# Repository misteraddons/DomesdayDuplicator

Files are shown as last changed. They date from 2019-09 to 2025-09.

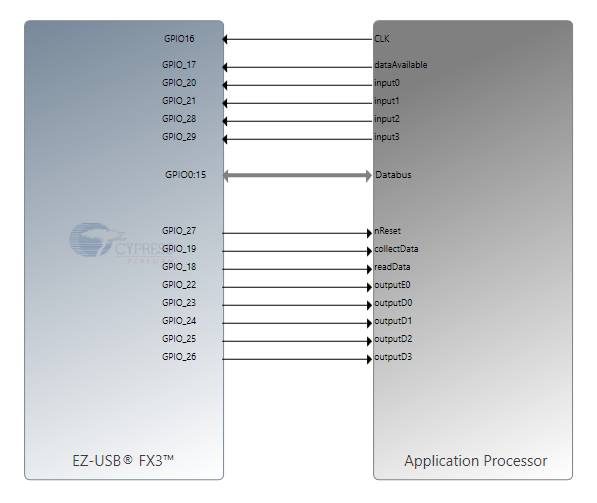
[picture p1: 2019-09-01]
Firmware/Cypress-FX3/GPIF_II/IO_Matrix_view.PNG

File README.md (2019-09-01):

# Domesday Duplicator

## Synopsis

The Domesday Duplicator is a USB3 based DAQ designed for the high-speed acquisition of analogue RF data.

The Domesday Duplicator was originally designed to allow the backup of Domesday AIV LaserDiscs (as well as generic laserdiscs) through the direct sampling of the RF data from the optical head (laser) of a LaserDisc player.  Since it's inception the project has expanded to include backup of other optical and magnetic media.

The hardware/software solution is designed to act as a sampling front-end to the ld-decode (software decode of laserdiscs) project https://github.com/happycube/ld-decode and can produce raw RF image files ready for software decoding.

Please see http://www.domesday86.com/?page_id=978 for detailed documentation on the Domesday Duplicator and overall information about the Domesday86 project.

There are several components that make up the Domesday Duplicator:

Terasic DE0-Nano FPGA development board - The DE0-Nano is a low-cost FPGA development board containing an Altera Cyclone IV FPGA.  The DE0-Nano is used to process the raw 10-bit ADC data stream and provides FIFO buffering (towards the FX3) and sample conversion from unsigned 10-bit to scaled 16-bit signed data.  The FPGA provides a dual-clock FIFO; receiving ADC data at a maximum of 40 MSPS (million samples per second) and transmitting the data to the FX3 at a maximum of 60 MSPS.  This is to ensure that no data is lost during sustained transfers (as RF sampling of a disc can take more than 40 minutes).

Cypress FX3 SuperSpeed Explorer board - The FX3 is a low-cost USB3 development board from Cypress.  The FX3 is used to buffer data from the FPGA and provide it to a host computer using USB3.  USB3 is required for this application due to the high-data bandwidth necessary for high-speed/high-resolution sampling.

Domesday Duplicator DE0-Nano base - This custom board provides the interface between the DE0-Nano and the Cypress FX3 board and contains 2 'slots' for Domesday Duplicator Modules.  As well as connectivity and databus routing the base board also contains the basic power supply circuitry for the modules.

Domesday Duplicator ADS825 module - A custom ADC board based around the Texas Instruments ADS825 10-Bit, 40MSPS analogue to digital converter. This board contains an RF amplifier and conditioner (to amplify the output from the laserdisc player RF tap and condition it for the single-ended ADC chip) as well as line-buffers to interface the ADC to the databus of the base board.

## Motivation

The Domesday86 project is involved in the documentation and preservation of the BBC Domesday Project from 1986.  The Domesday project provided a set of analogue laserdiscs in a proprietary format (like standard laserdiscs but with some specific extensions only supported by the Philips VP415 laserdisc player).

The Domesday Duplicator is intended to allow high-quality back-ups of the analogue information contained on the laserdiscs by bypassing most of the 30-year-old electronics in the VP415 player.  Direct RF sampling also allows all information on the laserdiscs to be stored (unlike conventional RGB sampling of the video output).  Since AIV laserdiscs are a combination of video, pictures, sound and data (as well as numerous VBI streams), direct RF sampling is the preferred method of preservation.

## Installation

Please see http://www.domesday86.com/?page_id=978 for detailed documentation on the Domesday Duplicator

## Author

Domesday Duplicator is written and maintained by Simon Inns.

## Software License (GPLv3)

    Domesday Duplicator is free software: you can redistribute it and/or modify
    it under the terms of the GNU General Public License as published by
    the Free Software Foundation, either version 3 of the License, or
    (at your option) any later version.

    Domesday Duplicator is distributed in the hope that it will be useful,
    but WITHOUT ANY WARRANTY; without even the implied warranty of
    MERCHANTABILITY or FITNESS FOR A PARTICULAR PURPOSE.  See the
    GNU General Public License for more details.

    You should have received a copy of the GNU General Public License
    along with this program.  If not, see <http://www.gnu.org/licenses/>.

## Hardware License (Creative Commons BY-SA 4.0)

Please see the following link for details: https://creativecommons.org/licenses/by-sa/4.0/

You are free to:

Share - copy and redistribute the material in any medium or format
Adapt - remix, transform, and build upon the material
for any purpose, even commercially.

This license is acceptable for Free Cultural Works.

The licensor cannot revoke these freedoms as long as you follow the license terms.

Under the following terms:

Attribution - You must give appropriate credit, provide a link to the license, and indicate if changes were made. You may do so in any reasonable manner, but not in any way that suggests the licensor endorses you or your use.

ShareAlike - If you remix, transform, or build upon the material, you must distribute your contributions under the same license as the original.

No additional restrictions - You may not apply legal terms or technological measures that legally restrict others from doing anything the license permits.

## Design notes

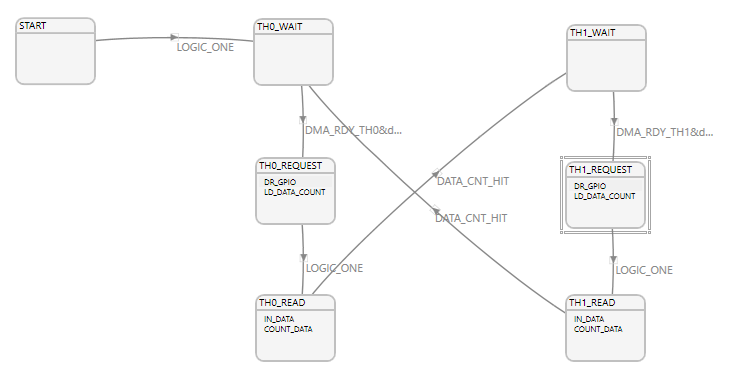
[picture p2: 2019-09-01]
Firmware/Cypress-FX3/GPIF_II/State_Machine_view.PNG

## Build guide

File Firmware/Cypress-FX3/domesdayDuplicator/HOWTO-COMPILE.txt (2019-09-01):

Setting up the Cypress tool-chain
=-=-=-=-=-=-=-=-=-=-=-=-=-=-=-=-=
Before compiling you must install the Cypress Linux SDK and follow the instructions in the 
FX3_SDK_Linux_Support PDF section 2.  The PDF is located in:

~/FX3_SDK_1.3.4_Linux/fx3_firmware_linux/cyfx3sdk

(Provided you copied the Cypress tarball to your home directory).

If you are running a 64-bit OS (which you should be) - follow section 2.1 step 3 and enter
the following command:

apt-get install lib32z1

No other parts of section 2.1 are required.

The section 2.2 instructions require you to set up a number of environment variables.  These
should be placed in your ~/.profile file so they are loaded everytime you log in.  The required
variables are as follows:

# Environment variables for Cypress FX3
export PATH=$PATH:$HOME/FX3_SDK_1.3.4_Linux/ARM_GCC/arm-2013.11/bin
export FX3_INSTALL_PATH=$HOME/FX3_SDK_1.3.4_Linux/fx3_firmware_linux/cyfx3sdk
export ARMGCC_INSTALL_PATH=$HOME/FX3_SDK_1.3.4_Linux/ARM_GCC/arm-2013.11
export ARMGCC_VERSION=4.8.1
export CYUSB_ROOT=$HOME/FX3_SDK_1.3.4_Linux/cyusb_linux_1.0.5

Once the environment variables are set (and you have loaded them by logging back into your
user account.  Compile the elf2img program as follows (section 2.1 step 7):

cd $FX3_INSTALL_PATH/util/elf2img
gcc elf2img.c –o elf2img –Wall

Compiling the Domesday Duplicator FX3 Firmware
=-=-=-=-=-=-=-=-=-=-=-=-=-=-=-=-=-=-=-=-=-=-=-
To compile the Domesday Duplicator FX3 firmware, first change directory to the source directory:

cd ~/github/FX3-Firmware/domesdayDuplicator

Then compile the firmware image using the command:

make all

Note: The Cypress version of Eclipse is *not* required.

Programming the FX3
=-=-=-=-=-=-=-=-=-=
To load the firmware onto the FX3 device use the Cypress cyusb_linux tool (please see the cypress
documentation for installation instructions).  The steps are as follows:

 1. Close/short jumper J4 (PMODE) on the FX3 Superspeed board
 2. Power off the FX3 and then power it on again
 3. Load the cyusb_linux application
 4. Highlight the FX3 bootloader device at the top of the window
 5. Click on the ‘program’ tab
 6. Select I2C EEPROM
 7. Click on ‘select file’ and select the FX3 programming file from disk (use the .img file from the Release directory)
 8. Click on ‘Start download’ to write the programming file to the device
 9. Wait for programming to complete
10. Remove the jumper from J4
11. Power off the FX3 and then power it on again

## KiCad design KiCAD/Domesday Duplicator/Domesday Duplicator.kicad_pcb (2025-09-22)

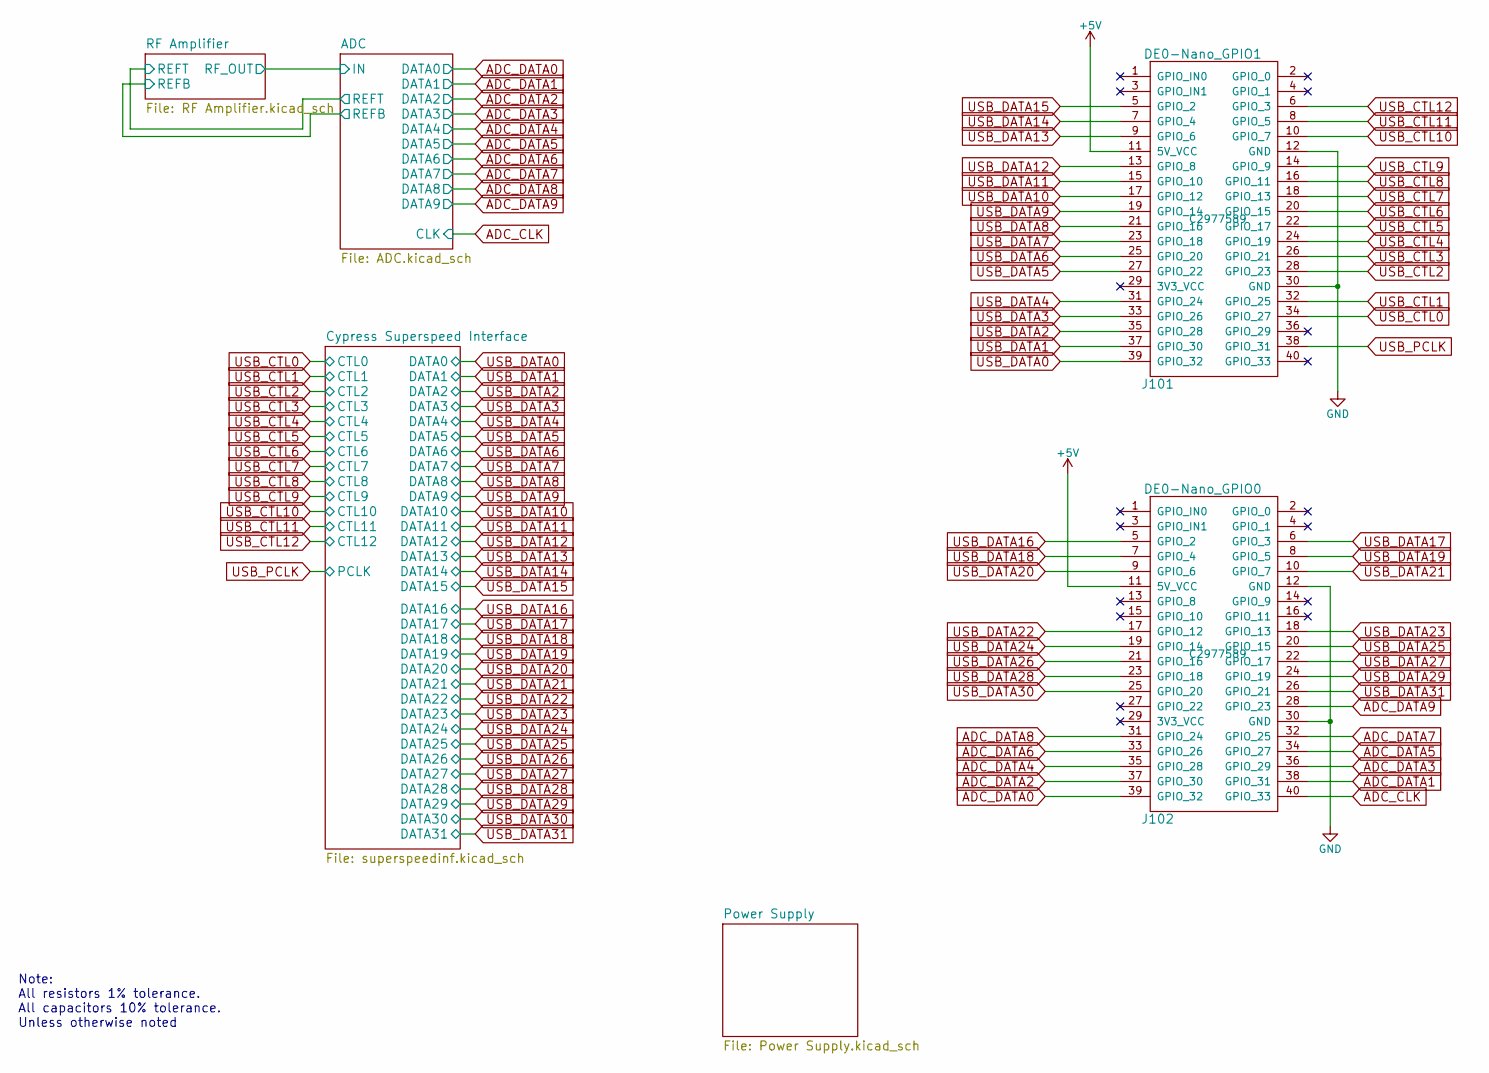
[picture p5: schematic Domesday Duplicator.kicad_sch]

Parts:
J101: DE0-Nano_GPIO1; PinSocket_2x20_P2.54mm_Vertical; LCSC Part C2977589
J102: DE0-Nano_GPIO0; PinSocket_2x20_P2.54mm_Vertical; LCSC Part C2977589

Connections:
+5V: J101.11 (5V_VCC), J102.11 (5V_VCC); also elsewhere on the board
ADC_CLK: J102.40 (GPIO_33); also elsewhere on the board
ADC_DATA0: J102.39 (GPIO_32); also elsewhere on the board
ADC_DATA1: J102.38 (GPIO_31); also elsewhere on the board
ADC_DATA2: J102.37 (GPIO_30); also elsewhere on the board
ADC_DATA3: J102.36 (GPIO_29); also elsewhere on the board
ADC_DATA4: J102.35 (GPIO_28); also elsewhere on the board
ADC_DATA5: J102.34 (GPIO_27); also elsewhere on the board
ADC_DATA6: J102.33 (GPIO_26); also elsewhere on the board
ADC_DATA7: J102.32 (GPIO_25); also elsewhere on the board
ADC_DATA8: J102.31 (GPIO_24); also elsewhere on the board
ADC_DATA9: J102.28 (GPIO_23); also elsewhere on the board
GND: J101.12 (GND), J101.30 (GND), J102.12 (GND), J102.30 (GND); also elsewhere on the board
USB_CTL0: J101.34 (GPIO_27); also elsewhere on the board
USB_CTL1: J101.32 (GPIO_25); also elsewhere on the board
USB_CTL2: J101.28 (GPIO_23); also elsewhere on the board
USB_CTL3: J101.26 (GPIO_21); also elsewhere on the board
USB_CTL4: J101.24 (GPIO_19); also elsewhere on the board
USB_CTL5: J101.22 (GPIO_17); also elsewhere on the board
USB_CTL6: J101.20 (GPIO_15); also elsewhere on the board
USB_CTL7: J101.18 (GPIO_13); also elsewhere on the board
USB_CTL8: J101.16 (GPIO_11); also elsewhere on the board
USB_CTL9: J101.14 (GPIO_9); also elsewhere on the board
USB_CTL10: J101.10 (GPIO_7); also elsewhere on the board
USB_CTL11: J101.8 (GPIO_5); also elsewhere on the board
USB_CTL12: J101.6 (GPIO_3); also elsewhere on the board
USB_DATA0: J101.39 (GPIO_32); also elsewhere on the board
USB_DATA1: J101.37 (GPIO_30); also elsewhere on the board
USB_DATA2: J101.35 (GPIO_28); also elsewhere on the board
USB_DATA3: J101.33 (GPIO_26); also elsewhere on the board
USB_DATA4: J101.31 (GPIO_24); also elsewhere on the board
USB_DATA5: J101.27 (GPIO_22); also elsewhere on the board
USB_DATA6: J101.25 (GPIO_20); also elsewhere on the board
USB_DATA7: J101.23 (GPIO_18); also elsewhere on the board
USB_DATA8: J101.21 (GPIO_16); also elsewhere on the board
USB_DATA9: J101.19 (GPIO_14); also elsewhere on the board
USB_DATA10: J101.17 (GPIO_12); also elsewhere on the board
USB_DATA11: J101.15 (GPIO_10); also elsewhere on the board
USB_DATA12: J101.13 (GPIO_8); also elsewhere on the board
USB_DATA13: J101.9 (GPIO_6); also elsewhere on the board
USB_DATA14: J101.7 (GPIO_4); also elsewhere on the board
USB_DATA15: J101.5 (GPIO_2); also elsewhere on the board
USB_DATA16: J102.5 (GPIO_2); also elsewhere on the board
USB_DATA17: J102.6 (GPIO_3); also elsewhere on the board
USB_DATA18: J102.7 (GPIO_4); also elsewhere on the board
USB_DATA19: J102.8 (GPIO_5); also elsewhere on the board
USB_DATA20: J102.9 (GPIO_6); also elsewhere on the board
USB_DATA21: J102.10 (GPIO_7); also elsewhere on the board
USB_DATA22: J102.17 (GPIO_12); also elsewhere on the board
USB_DATA23: J102.18 (GPIO_13); also elsewhere on the board
USB_DATA24: J102.19 (GPIO_14); also elsewhere on the board
USB_DATA25: J102.20 (GPIO_15); also elsewhere on the board
USB_DATA26: J102.21 (GPIO_16); also elsewhere on the board
USB_DATA27: J102.22 (GPIO_17); also elsewhere on the board
USB_DATA28: J102.23 (GPIO_18); also elsewhere on the board
USB_DATA29: J102.24 (GPIO_19); also elsewhere on the board
USB_DATA30: J102.25 (GPIO_20); also elsewhere on the board
USB_DATA31: J102.26 (GPIO_21); also elsewhere on the board
USB_PCLK: J101.38 (GPIO_31); also elsewhere on the board

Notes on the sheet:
Note: All resistors 1% tolerance. All capacitors 10% tolerance. Unless otherwise noted

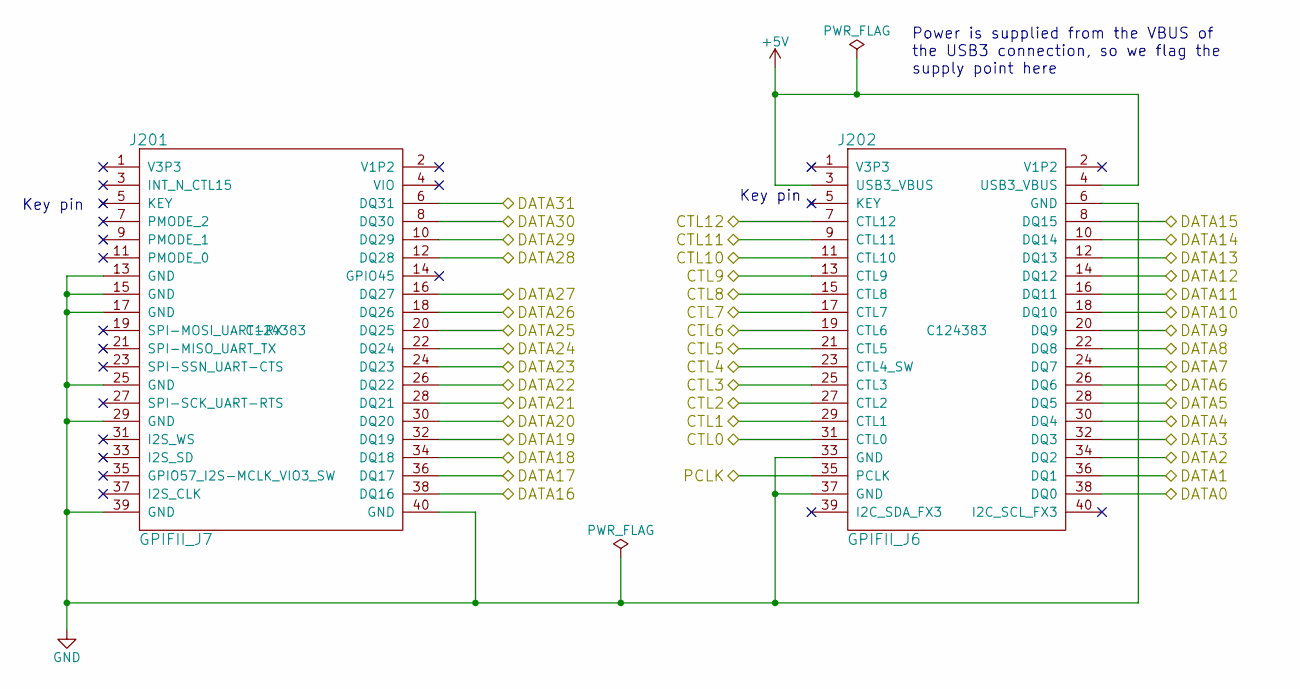
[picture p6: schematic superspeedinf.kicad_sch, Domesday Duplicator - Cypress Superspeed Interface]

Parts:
J201: GPIFII_J7; PinHeader_2x20_P2.54mm_Vertical; LCSC Part C124383
J202: GPIFII_J6; PinHeader_2x20_P2.54mm_Vertical; LCSC Part C124383

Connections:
+5V: J202.3 (USB3_VBUS), J202.4 (USB3_VBUS); also elsewhere on the board
GND: J201.13 (GND), J201.15 (GND), J201.17 (GND), J201.25 (GND), J201.29 (GND), J201.39 (GND), J201.40 (GND), J202.6 (GND), J202.33 (GND), J202.37 (GND); also elsewhere on the board
USB_CTL0: J202.31 (CTL0); also elsewhere on the board
USB_CTL1: J202.29 (CTL1); also elsewhere on the board
USB_CTL2: J202.27 (CTL2); also elsewhere on the board
USB_CTL3: J202.25 (CTL3); also elsewhere on the board
USB_CTL4: J202.23 (CTL4_SW); also elsewhere on the board
USB_CTL5: J202.21 (CTL5); also elsewhere on the board
USB_CTL6: J202.19 (CTL6); also elsewhere on the board
USB_CTL7: J202.17 (CTL7); also elsewhere on the board
USB_CTL8: J202.15 (CTL8); also elsewhere on the board
USB_CTL9: J202.13 (CTL9); also elsewhere on the board
USB_CTL10: J202.11 (CTL10); also elsewhere on the board
USB_CTL11: J202.9 (CTL11); also elsewhere on the board
USB_CTL12: J202.7 (CTL12); also elsewhere on the board
USB_DATA0: J202.38 (DQ0); also elsewhere on the board
USB_DATA1: J202.36 (DQ1); also elsewhere on the board
USB_DATA2: J202.34 (DQ2); also elsewhere on the board
USB_DATA3: J202.32 (DQ3); also elsewhere on the board
USB_DATA4: J202.30 (DQ4); also elsewhere on the board
USB_DATA5: J202.28 (DQ5); also elsewhere on the board
USB_DATA6: J202.26 (DQ6); also elsewhere on the board
USB_DATA7: J202.24 (DQ7); also elsewhere on the board
USB_DATA8: J202.22 (DQ8); also elsewhere on the board
USB_DATA9: J202.20 (DQ9); also elsewhere on the board
USB_DATA10: J202.18 (DQ10); also elsewhere on the board
USB_DATA11: J202.16 (DQ11); also elsewhere on the board
USB_DATA12: J202.14 (DQ12); also elsewhere on the board
USB_DATA13: J202.12 (DQ13); also elsewhere on the board
USB_DATA14: J202.10 (DQ14); also elsewhere on the board
USB_DATA15: J202.8 (DQ15); also elsewhere on the board
USB_DATA16: J201.38 (DQ16); also elsewhere on the board
USB_DATA17: J201.36 (DQ17); also elsewhere on the board
USB_DATA18: J201.34 (DQ18); also elsewhere on the board
USB_DATA19: J201.32 (DQ19); also elsewhere on the board
USB_DATA20: J201.30 (DQ20); also elsewhere on the board
USB_DATA21: J201.28 (DQ21); also elsewhere on the board
USB_DATA22: J201.26 (DQ22); also elsewhere on the board
USB_DATA23: J201.24 (DQ23); also elsewhere on the board
USB_DATA24: J201.22 (DQ24); also elsewhere on the board
USB_DATA25: J201.20 (DQ25); also elsewhere on the board
USB_DATA26: J201.18 (DQ26); also elsewhere on the board
USB_DATA27: J201.16 (DQ27); also elsewhere on the board
USB_DATA28: J201.12 (DQ28); also elsewhere on the board
USB_DATA29: J201.10 (DQ29); also elsewhere on the board
USB_DATA30: J201.8 (DQ30); also elsewhere on the board
USB_DATA31: J201.6 (DQ31); also elsewhere on the board
USB_PCLK: J202.35 (PCLK); also elsewhere on the board

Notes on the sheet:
Power is supplied from the VBUS of the USB3 connection, so we flag the supply point here
Key pin

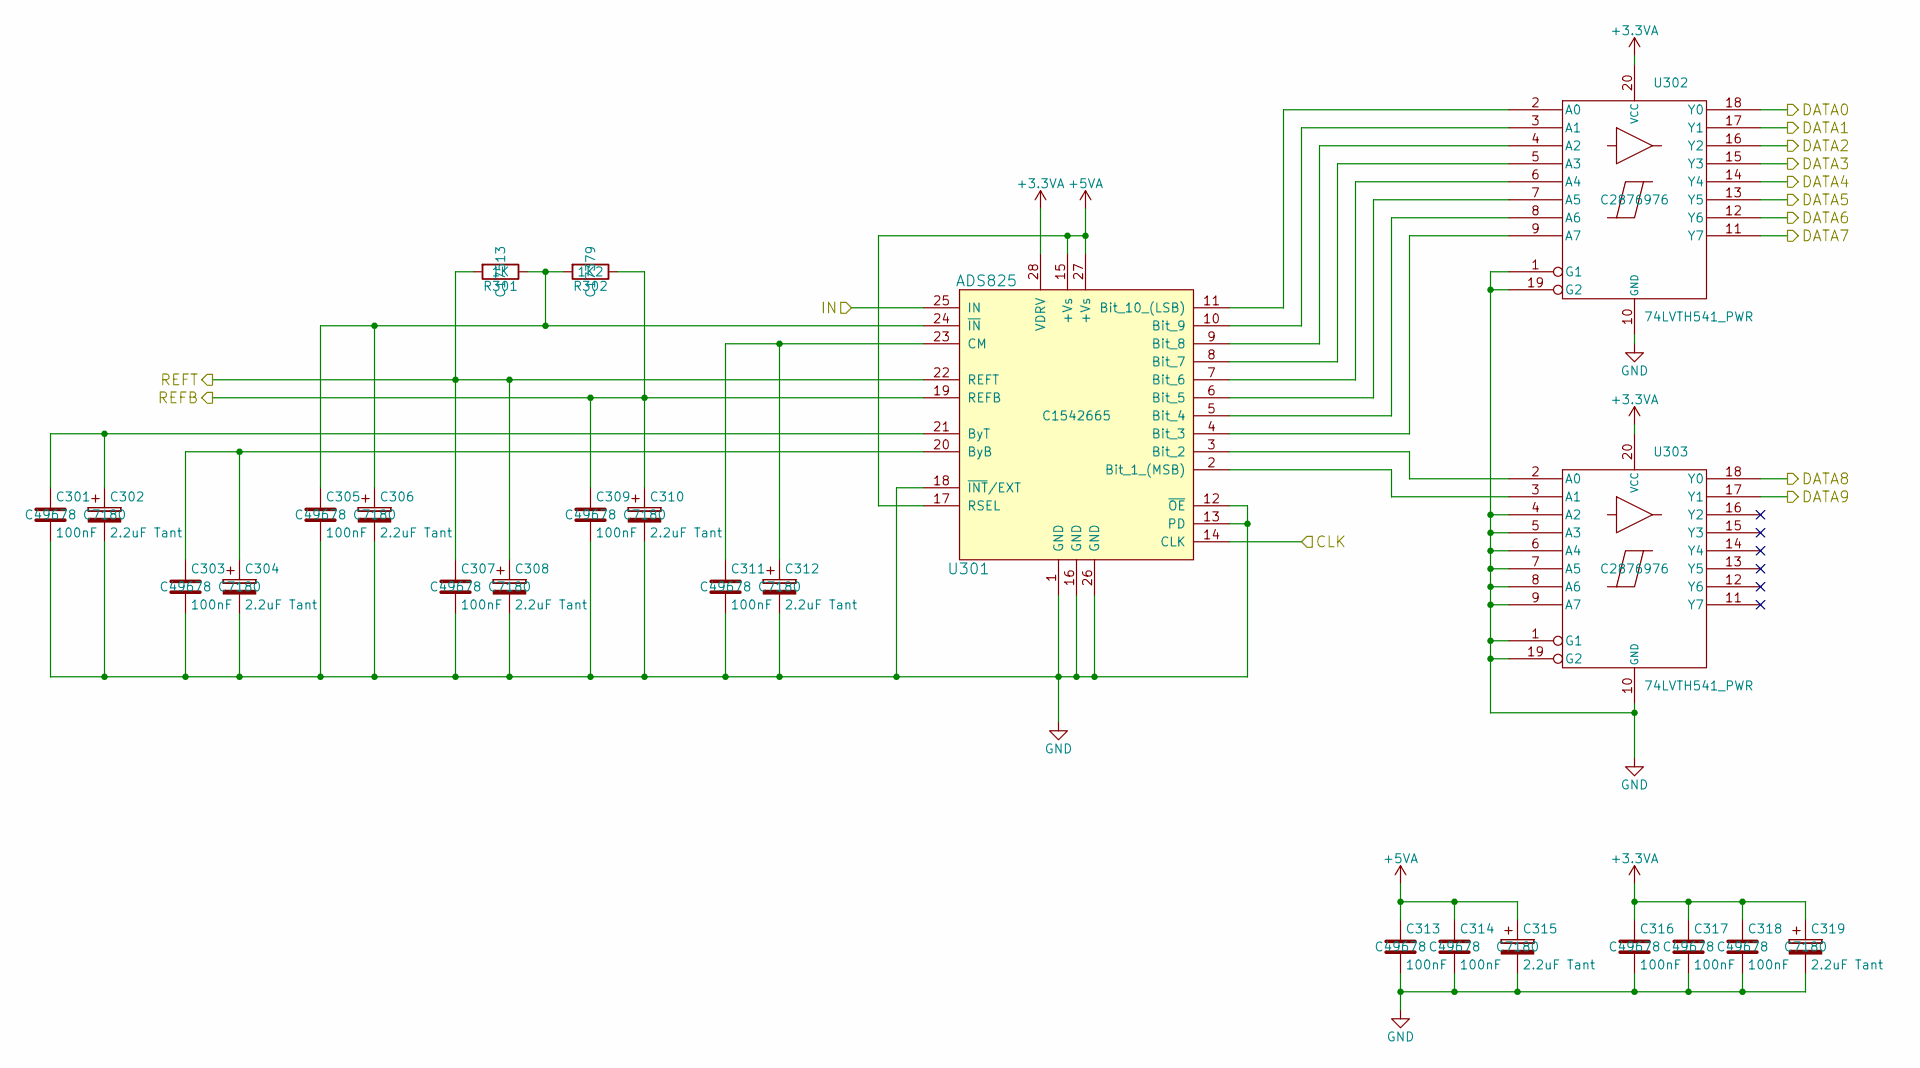
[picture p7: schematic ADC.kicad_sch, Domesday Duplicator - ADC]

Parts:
C301, C303, C305, C307, C309, C311, C313, C314, C316, C317, C318: 100nF; C_0805; LCSC Part C49678
C302, C304, C306, C308, C310, C312, C315, C319: 2.2uF Tant; CP_Tantalum_Case-A_EIA-3216-18_Reflow; LCSC Part C7180
R301: 1K; R_0805; LCSC Part C17513
R302: 1K2; R_0805; LCSC Part C17379
U301: ADS825; SSOP-28_5.3x10.2mm_Pitch0.65mm; LCSC Part C1542665
U302, U303: 74LVTH541_PWR; TSSOP-20_4.4x6.5mm_Pitch0.65mm; LCSC Part C2876976

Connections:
+3.3VA: C316.1, C317.1, C318.1, C319.1, U301.28 (VDRV), U302.20 (VCC), U303.20 (VCC); also elsewhere on the board
+5VA: C313.1, C314.1, C315.1, U301.15 (+Vs), U301.17 (RSEL), U301.27 (+Vs); also elsewhere on the board
/ADC/IN: U301.25 (IN); also elsewhere on the board
/ADC/REFB: C309.1, C310.1, R302.1, U301.19 (REFB); also elsewhere on the board
/ADC/REFT: C307.1, C308.1, R301.2, U301.22 (REFT); also elsewhere on the board
ADC_CLK: U301.14 (CLK); also elsewhere on the board
ADC_DATA0: U302.18 (Y0); also elsewhere on the board
ADC_DATA1: U302.17 (Y1); also elsewhere on the board
ADC_DATA2: U302.16 (Y2); also elsewhere on the board
ADC_DATA3: U302.15 (Y3); also elsewhere on the board
ADC_DATA4: U302.14 (Y4); also elsewhere on the board
ADC_DATA5: U302.13 (Y5); also elsewhere on the board
ADC_DATA6: U302.12 (Y6); also elsewhere on the board
ADC_DATA7: U302.11 (Y7); also elsewhere on the board
ADC_DATA8: U303.18 (Y0); also elsewhere on the board
ADC_DATA9: U303.17 (Y1); also elsewhere on the board
GND: C301.2, C302.2, C303.2, C304.2, C305.2, C306.2, C307.2, C308.2, C309.2, C310.2, C311.2, C312.2, C313.2, C314.2, C315.2, C316.2, C317.2, C318.2, C319.2, U301.1 (GND), U301.12 (~OE), U301.13 (PD), U301.16 (GND), U301.18 (~INT/EXT), U301.26 (GND), U302.1 (G1), U302.10 (GND), U302.19 (G2), U303.1 (G1), U303.4 (A2), U303.5 (A3), U303.6 (A4), U303.7 (A5), U303.8 (A6), U303.9 (A7), U303.10 (GND), U303.19 (G2); also elsewhere on the board
unnamed: U301.2 (Bit_1_(MSB)), U303.3 (A1)
unnamed: U301.3 (Bit_2), U303.2 (A0)
unnamed: U301.4 (Bit_3), U302.9 (A7)
unnamed: U301.5 (Bit_4), U302.8 (A6)
unnamed: U301.6 (Bit_5), U302.7 (A5)
unnamed: U301.7 (Bit_6), U302.6 (A4)
unnamed: U301.8 (Bit_7), U302.5 (A3)
unnamed: U301.9 (Bit_8), U302.4 (A2)
unnamed: U301.10 (Bit_9), U302.3 (A1)
unnamed: U301.11 (Bit_10_(LSB)), U302.2 (A0)
unnamed: C303.1, C304.1, U301.20 (ByB)
unnamed: C301.1, C302.1, U301.21 (ByT)
unnamed: C311.1, C312.1, U301.23 (CM)
unnamed: C305.1, C306.1, R301.1, R302.2, U301.24 (~IN)

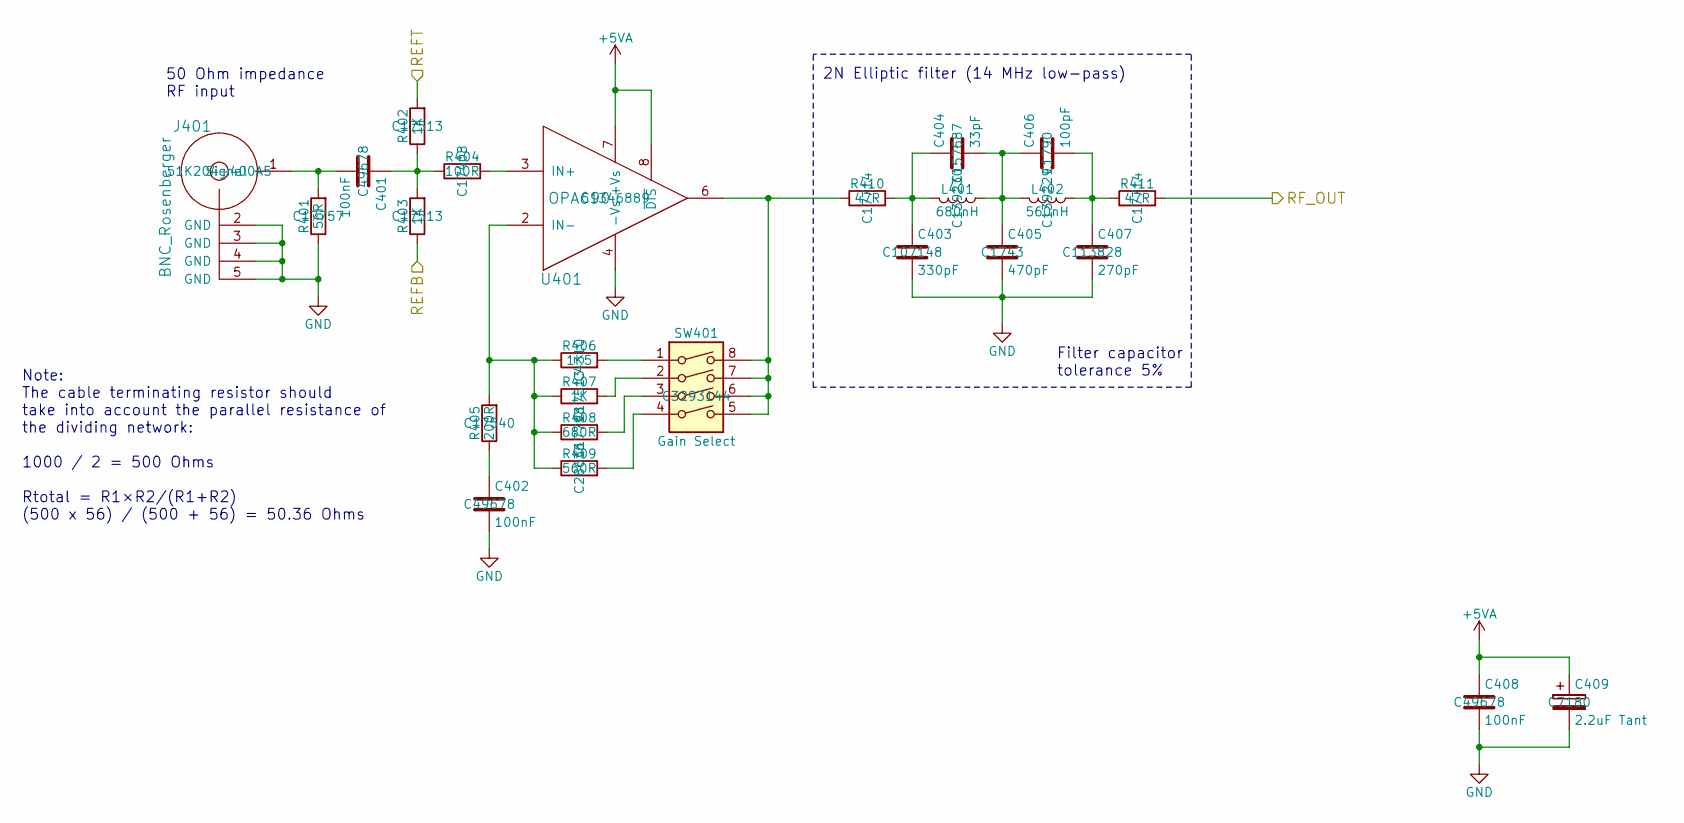
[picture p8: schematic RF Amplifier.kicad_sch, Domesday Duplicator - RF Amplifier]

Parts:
C401, C402, C408: 100nF; C_0805; LCSC Part C49678
C403: 330pF; C_0805; LCSC Part C107148
C404: 33pF; C_0805; LCSC Part C157687
C405: 470pF; C_0805; LCSC Part C1743
C406: 100pF; C_0805; LCSC Part C1790
C407: 270pF; C_0805; LCSC Part C113828
C409: 2.2uF Tant; CP_Tantalum_Case-A_EIA-3216-18_Reflow; LCSC Part C7180
J401: BNC_Rosenberger; BNC Socket; LCSC Part 51K204-400A5
L401: 680nH; L_0805; LCSC Part C139230
L402: 560nH; L_0805; LCSC Part C139229
R401: 56R; R_0805; LCSC Part C17757
R402, R403, R407: 1K; R_0805; LCSC Part C17513
R404: 100R; R_0805; LCSC Part C17408
R405: 200R; R_0805; LCSC Part C17540
R406: 1K5; R_0805; LCSC Part C4310
R408: 680R; R_0805; LCSC Part C17798
R409: 560R; R_0805; LCSC Part C28636
R410, R411: 47R; R_0805; LCSC Part C17714
SW401: Gain Select; SW_DIP_x4_W7.62mm_Slide_Copal_CHS-B; LCSC Part C3293144
U401: OPA690; SOIC-8_3.9x4.9mm_Pitch1.27mm; LCSC Part C1346889

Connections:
+5VA: C408.1, C409.1, U401.7 (+Vs), U401.8 (~DIS); also elsewhere on the board
/ADC/IN: R411.2; also elsewhere on the board
/ADC/REFB: R403.1; also elsewhere on the board
/ADC/REFT: R402.2; also elsewhere on the board
GND: C402.2, C403.2, C405.2, C407.2, C408.2, C409.2, J401.2 (GND), J401.3 (GND), J401.4 (GND), J401.5 (GND), R401.1, U401.4 (-Vs); also elsewhere on the board
unnamed: C401.1, R402.1, R403.2, R404.1
unnamed: C402.1, R405.1
unnamed: C403.1, C404.1, L401.2, R410.2
unnamed: C404.2, C405.1, C406.1, L401.1, L402.2
unnamed: C406.2, C407.1, L402.1, R411.1
unnamed: C401.2, J401.1 (Signal), R401.2
unnamed: R406.2, SW401.1
unnamed: R407.2, SW401.2
unnamed: R408.2, SW401.3
unnamed: R409.2, SW401.4
unnamed: R404.2, U401.3 (IN+)
unnamed: R405.2, R406.1, R407.1, R408.1, R409.1, U401.2 (IN-)
unnamed: R410.1, SW401.5, SW401.6, SW401.7, SW401.8, U401.6 (Output)

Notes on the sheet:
Note: The cable terminating resistor should take into account the parallel resistance of the dividing network: 1000 / 2 = 500 Ohms Rtotal = R1×R2/(R1+R2) (500 x 56) / (500 + 56) = 50.36 Ohms
2N Elliptic filter (14 MHz low-pass)
50 Ohm impedance RF input
Filter capacitor tolerance 5%

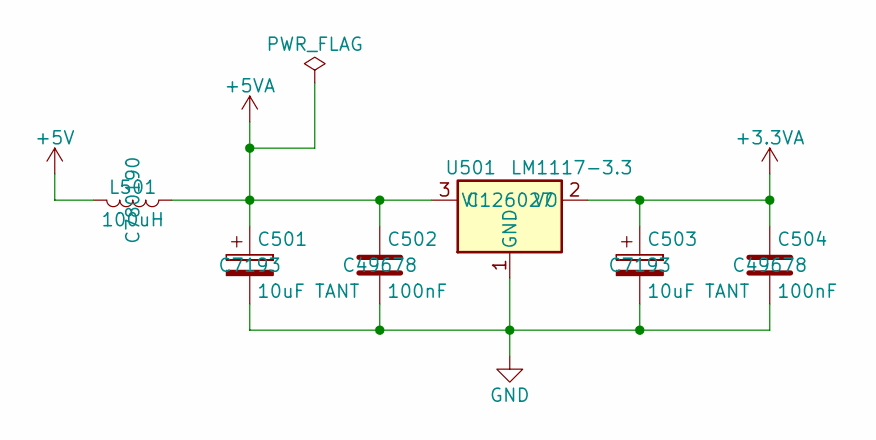
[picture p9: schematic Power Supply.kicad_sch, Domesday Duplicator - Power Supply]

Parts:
C501, C503: 10uF TANT; CP_Tantalum_Case-B_EIA-3528-21_Reflow; LCSC Part C7193
C502, C504: 100nF; C_0805; LCSC Part C49678
L501: 100uH; Inductor_Bourns-SRU8043; LCSC Part C780190
U501: LM1117-3.3; SOT-223-3_TabPin2; LCSC Part C126027

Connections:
+3.3VA: C503.1, C504.1, U501.2 (VO); also elsewhere on the board
+5V: L501.2; also elsewhere on the board
+5VA: C501.1, C502.1, L501.1, U501.3 (VI); also elsewhere on the board
GND: C501.2, C502.2, C503.2, C504.2, U501.1 (GND); also elsewhere on the board

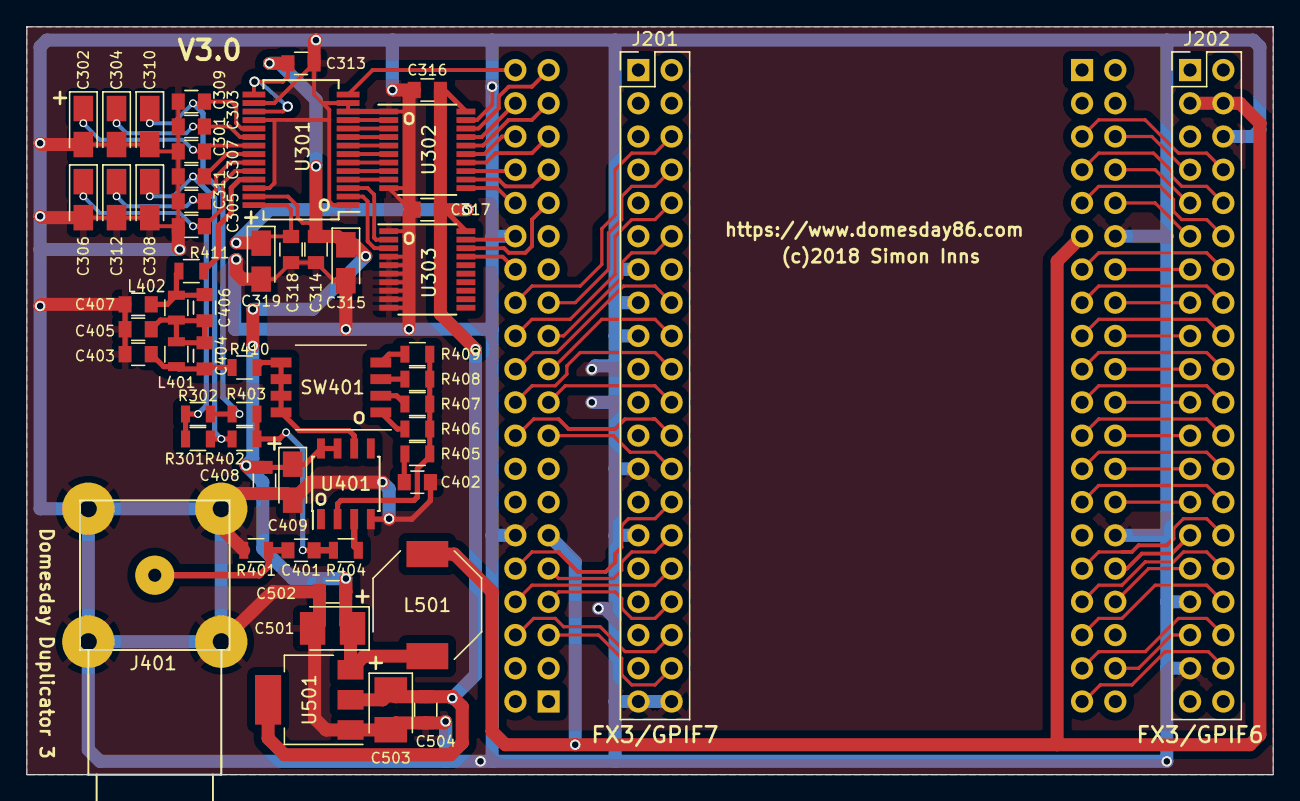
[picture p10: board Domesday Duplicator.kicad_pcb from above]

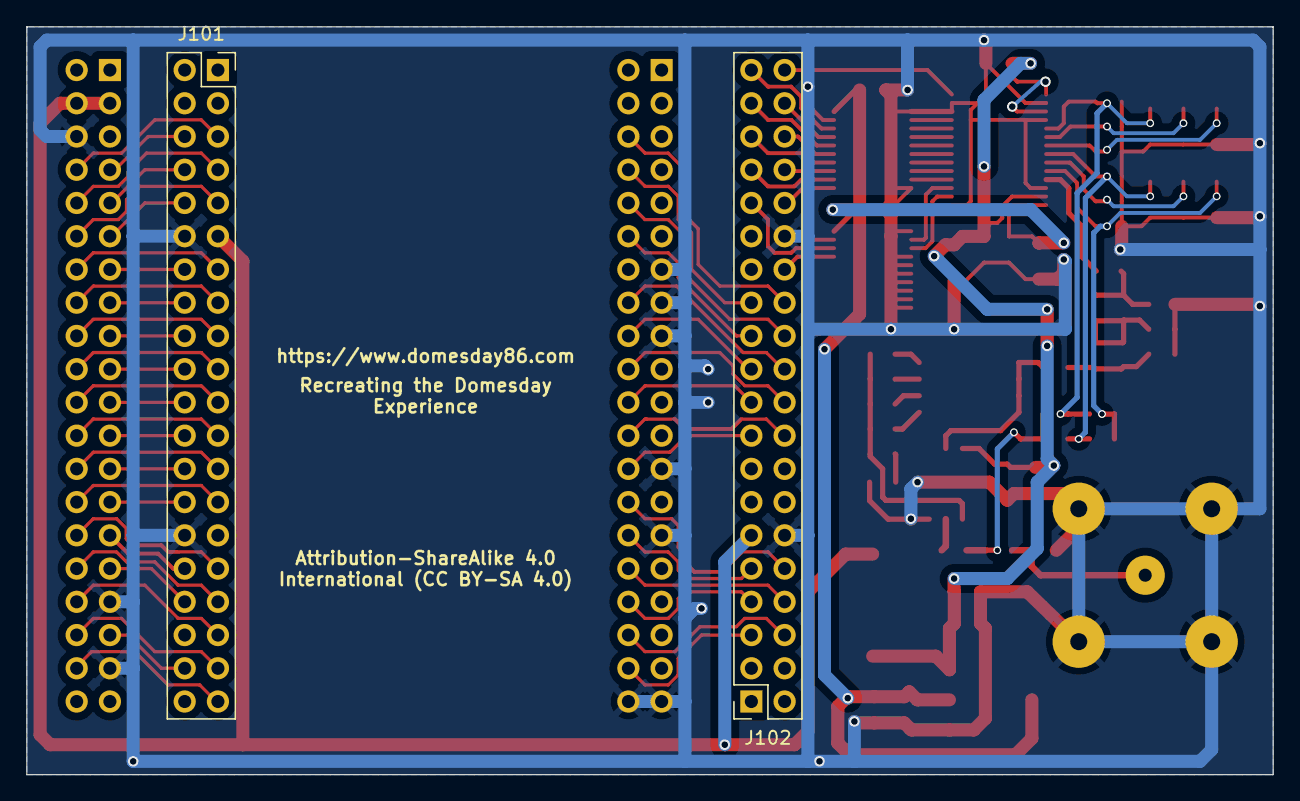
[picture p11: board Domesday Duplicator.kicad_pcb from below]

Board: 2 copper layers, 95.2 x 57.2 mm, 59 parts (2 on the bottom side), 91 nets.

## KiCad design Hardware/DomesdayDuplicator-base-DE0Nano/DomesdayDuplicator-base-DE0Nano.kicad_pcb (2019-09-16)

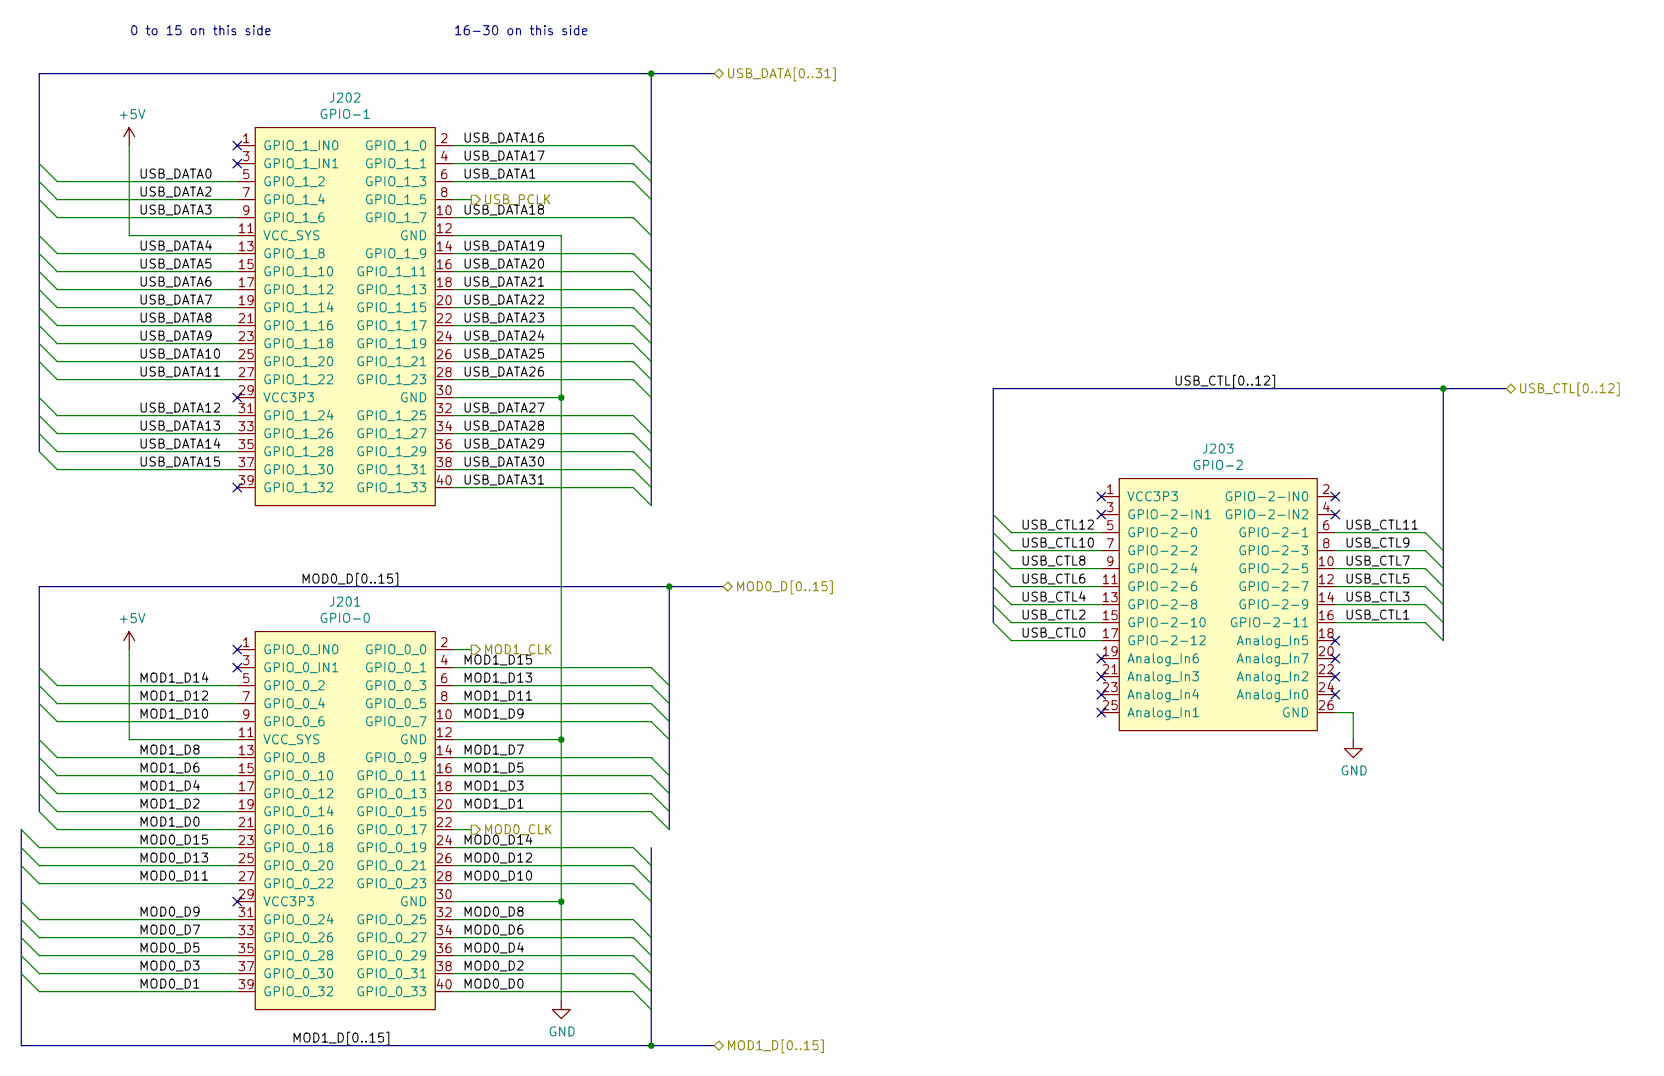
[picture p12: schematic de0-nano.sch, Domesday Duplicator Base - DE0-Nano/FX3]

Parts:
J201: GPIO-0; PinSocket_2x20_P2.54mm_Vertical
J202: GPIO-1; PinSocket_2x20_P2.54mm_Vertical
J203: GPIO-2; IDC-Header_2x13_P2.54mm_Horizontal

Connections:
+5V: J201.11 (VCC_SYS), J202.11 (VCC_SYS); also elsewhere on the board
/Cypress FX3/USB_CTL0: J203.17 (GPIO-2-12); also elsewhere on the board
/Cypress FX3/USB_CTL1: J203.16 (GPIO-2-11); also elsewhere on the board
/Cypress FX3/USB_CTL2: J203.15 (GPIO-2-10); also elsewhere on the board
/Cypress FX3/USB_CTL3: J203.14 (GPIO-2-9); also elsewhere on the board
/Cypress FX3/USB_CTL4: J203.13 (GPIO-2-8); also elsewhere on the board
/Cypress FX3/USB_CTL5: J203.12 (GPIO-2-7); also elsewhere on the board
/Cypress FX3/USB_CTL6: J203.11 (GPIO-2-6); also elsewhere on the board
/Cypress FX3/USB_CTL7: J203.10 (GPIO-2-5); also elsewhere on the board
/Cypress FX3/USB_CTL8: J203.9 (GPIO-2-4); also elsewhere on the board
/Cypress FX3/USB_CTL9: J203.8 (GPIO-2-3); also elsewhere on the board
/Cypress FX3/USB_CTL10: J203.7 (GPIO-2-2); also elsewhere on the board
/Cypress FX3/USB_CTL11: J203.6 (GPIO-2-1); also elsewhere on the board
/Cypress FX3/USB_CTL12: J203.5 (GPIO-2-0); also elsewhere on the board
/Cypress FX3/USB_DATA0: J202.5 (GPIO_1_2); also elsewhere on the board
/Cypress FX3/USB_DATA1: J202.6 (GPIO_1_3); also elsewhere on the board
/Cypress FX3/USB_DATA2: J202.7 (GPIO_1_4); also elsewhere on the board
/Cypress FX3/USB_DATA3: J202.9 (GPIO_1_6); also elsewhere on the board
/Cypress FX3/USB_DATA4: J202.13 (GPIO_1_8); also elsewhere on the board
/Cypress FX3/USB_DATA5: J202.15 (GPIO_1_10); also elsewhere on the board
/Cypress FX3/USB_DATA6: J202.17 (GPIO_1_12); also elsewhere on the board
/Cypress FX3/USB_DATA7: J202.19 (GPIO_1_14); also elsewhere on the board
/Cypress FX3/USB_DATA8: J202.21 (GPIO_1_16); also elsewhere on the board
/Cypress FX3/USB_DATA9: J202.23 (GPIO_1_18); also elsewhere on the board
/Cypress FX3/USB_DATA10: J202.25 (GPIO_1_20); also elsewhere on the board
/Cypress FX3/USB_DATA11: J202.27 (GPIO_1_22); also elsewhere on the board
/Cypress FX3/USB_DATA12: J202.31 (GPIO_1_24); also elsewhere on the board
/Cypress FX3/USB_DATA13: J202.33 (GPIO_1_26); also elsewhere on the board
/Cypress FX3/USB_DATA14: J202.35 (GPIO_1_28); also elsewhere on the board
/Cypress FX3/USB_DATA15: J202.37 (GPIO_1_30); also elsewhere on the board
/Cypress FX3/USB_DATA16: J202.2 (GPIO_1_0); also elsewhere on the board
/Cypress FX3/USB_DATA17: J202.4 (GPIO_1_1); also elsewhere on the board
/Cypress FX3/USB_DATA18: J202.10 (GPIO_1_7); also elsewhere on the board
/Cypress FX3/USB_DATA19: J202.14 (GPIO_1_9); also elsewhere on the board
/Cypress FX3/USB_DATA20: J202.16 (GPIO_1_11); also elsewhere on the board
/Cypress FX3/USB_DATA21: J202.18 (GPIO_1_13); also elsewhere on the board
/Cypress FX3/USB_DATA22: J202.20 (GPIO_1_15); also elsewhere on the board
/Cypress FX3/USB_DATA23: J202.22 (GPIO_1_17); also elsewhere on the board
/Cypress FX3/USB_DATA24: J202.24 (GPIO_1_19); also elsewhere on the board
/Cypress FX3/USB_DATA25: J202.26 (GPIO_1_21); also elsewhere on the board
/Cypress FX3/USB_DATA26: J202.28 (GPIO_1_23); also elsewhere on the board
/Cypress FX3/USB_DATA27: J202.32 (GPIO_1_25); also elsewhere on the board
/Cypress FX3/USB_DATA28: J202.34 (GPIO_1_27); also elsewhere on the board
/Cypress FX3/USB_DATA29: J202.36 (GPIO_1_29); also elsewhere on the board
/Cypress FX3/USB_DATA30: J202.38 (GPIO_1_31); also elsewhere on the board
/Cypress FX3/USB_DATA31: J202.40 (GPIO_1_33); also elsewhere on the board
/Cypress FX3/USB_PCLK: J202.8 (GPIO_1_5); also elsewhere on the board
/DE0-Nano/MOD0_CLK: J201.22 (GPIO_0_17); also elsewhere on the board
/DE0-Nano/MOD0_D0: J201.40 (GPIO_0_33); also elsewhere on the board
/DE0-Nano/MOD0_D1: J201.39 (GPIO_0_32); also elsewhere on the board
/DE0-Nano/MOD0_D2: J201.38 (GPIO_0_31); also elsewhere on the board
/DE0-Nano/MOD0_D3: J201.37 (GPIO_0_30); also elsewhere on the board
/DE0-Nano/MOD0_D4: J201.36 (GPIO_0_29); also elsewhere on the board
/DE0-Nano/MOD0_D5: J201.35 (GPIO_0_28); also elsewhere on the board
/DE0-Nano/MOD0_D6: J201.34 (GPIO_0_27); also elsewhere on the board
/DE0-Nano/MOD0_D7: J201.33 (GPIO_0_26); also elsewhere on the board
/DE0-Nano/MOD0_D8: J201.32 (GPIO_0_25); also elsewhere on the board
/DE0-Nano/MOD0_D9: J201.31 (GPIO_0_24); also elsewhere on the board
/DE0-Nano/MOD0_D10: J201.28 (GPIO_0_23); also elsewhere on the board
/DE0-Nano/MOD0_D11: J201.27 (GPIO_0_22); also elsewhere on the board
/DE0-Nano/MOD0_D12: J201.26 (GPIO_0_21); also elsewhere on the board
/DE0-Nano/MOD0_D13: J201.25 (GPIO_0_20); also elsewhere on the board
/DE0-Nano/MOD0_D14: J201.24 (GPIO_0_19); also elsewhere on the board
/DE0-Nano/MOD0_D15: J201.23 (GPIO_0_18); also elsewhere on the board
/DE0-Nano/MOD1_CLK: J201.2 (GPIO_0_0); also elsewhere on the board
/DE0-Nano/MOD1_D0: J201.21 (GPIO_0_16); also elsewhere on the board
/DE0-Nano/MOD1_D1: J201.20 (GPIO_0_15); also elsewhere on the board
/DE0-Nano/MOD1_D2: J201.19 (GPIO_0_14); also elsewhere on the board
/DE0-Nano/MOD1_D3: J201.18 (GPIO_0_13); also elsewhere on the board
/DE0-Nano/MOD1_D4: J201.17 (GPIO_0_12); also elsewhere on the board
/DE0-Nano/MOD1_D5: J201.16 (GPIO_0_11); also elsewhere on the board
/DE0-Nano/MOD1_D6: J201.15 (GPIO_0_10); also elsewhere on the board
/DE0-Nano/MOD1_D7: J201.14 (GPIO_0_9); also elsewhere on the board
/DE0-Nano/MOD1_D8: J201.13 (GPIO_0_8); also elsewhere on the board
/DE0-Nano/MOD1_D9: J201.10 (GPIO_0_7); also elsewhere on the board
/DE0-Nano/MOD1_D10: J201.9 (GPIO_0_6); also elsewhere on the board
/DE0-Nano/MOD1_D11: J201.8 (GPIO_0_5); also elsewhere on the board
/DE0-Nano/MOD1_D12: J201.7 (GPIO_0_4); also elsewhere on the board
/DE0-Nano/MOD1_D13: J201.6 (GPIO_0_3); also elsewhere on the board
/DE0-Nano/MOD1_D14: J201.5 (GPIO_0_2); also elsewhere on the board
/DE0-Nano/MOD1_D15: J201.4 (GPIO_0_1); also elsewhere on the board
GND: J201.12 (GND), J201.30 (GND), J202.12 (GND), J202.30 (GND), J203.26 (GND); also elsewhere on the board

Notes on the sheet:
0 to 15 on this side
16-30 on this side

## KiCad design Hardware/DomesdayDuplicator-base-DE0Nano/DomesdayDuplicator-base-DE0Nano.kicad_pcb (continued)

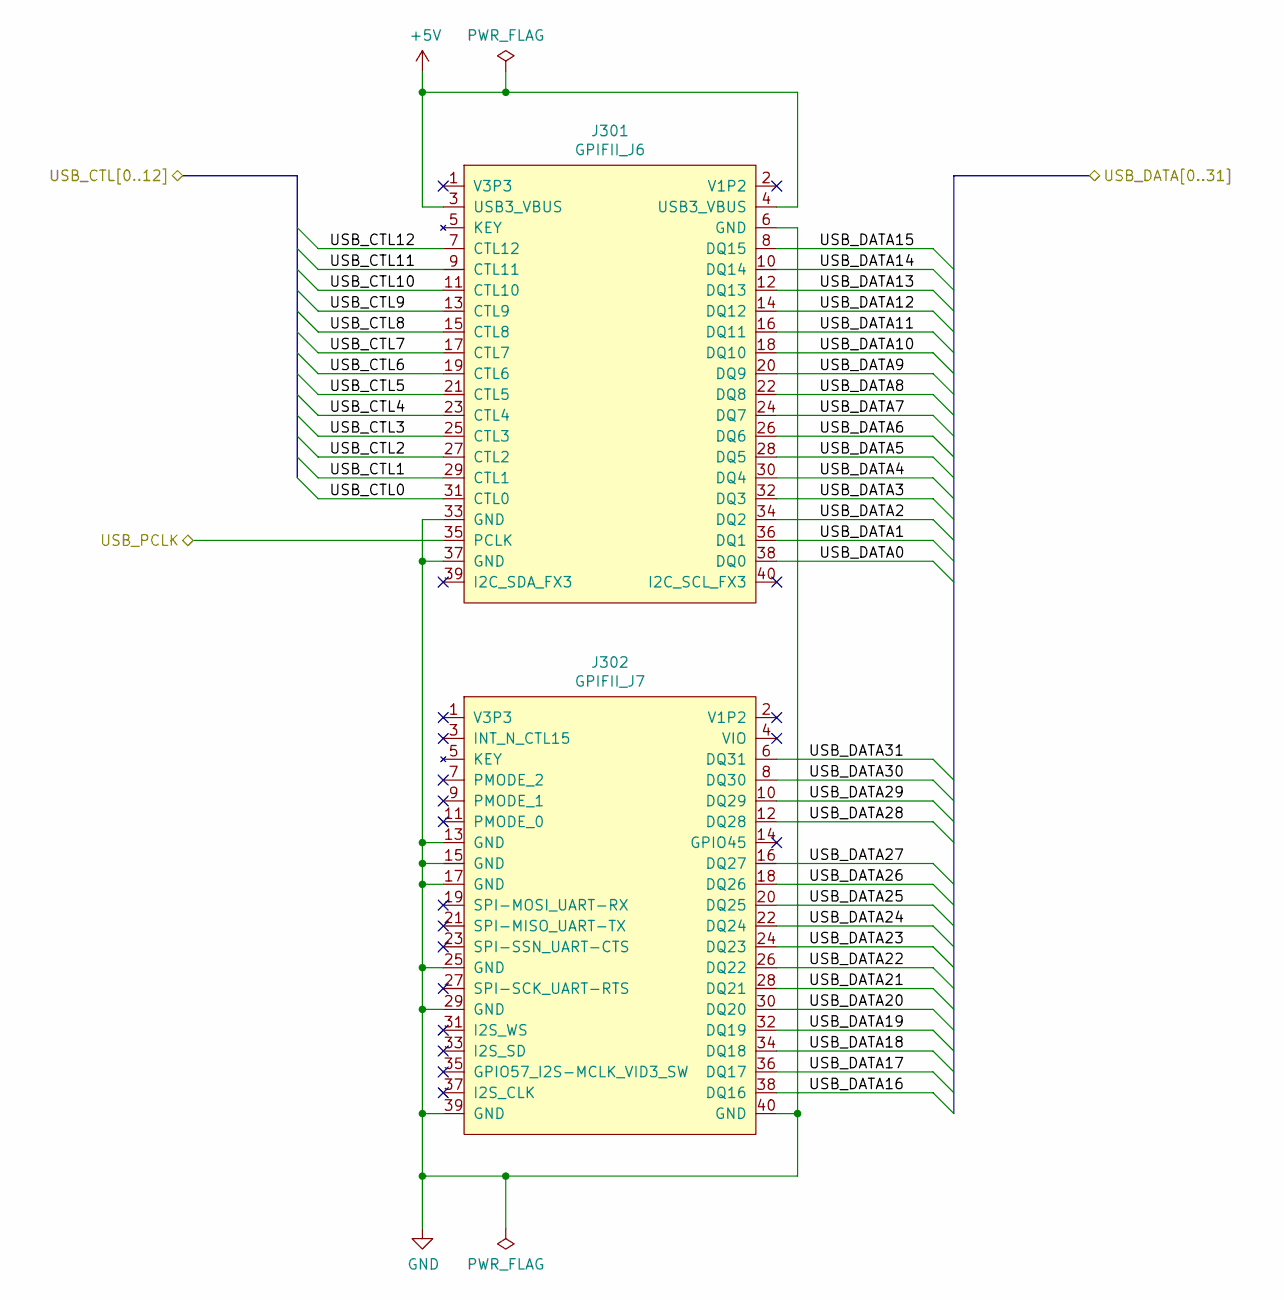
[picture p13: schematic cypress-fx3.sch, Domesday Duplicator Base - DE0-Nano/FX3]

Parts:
J301: GPIFII_J6; PinHeader_2x20_P2.54mm_Vertical
J302: GPIFII_J7; PinHeader_2x20_P2.54mm_Vertical

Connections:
+5V: J301.3 (USB3_VBUS), J301.4 (USB3_VBUS); also elsewhere on the board
/Cypress FX3/USB_CTL0: J301.31 (CTL0); also elsewhere on the board
/Cypress FX3/USB_CTL1: J301.29 (CTL1); also elsewhere on the board
/Cypress FX3/USB_CTL2: J301.27 (CTL2); also elsewhere on the board
/Cypress FX3/USB_CTL3: J301.25 (CTL3); also elsewhere on the board
/Cypress FX3/USB_CTL4: J301.23 (CTL4); also elsewhere on the board
/Cypress FX3/USB_CTL5: J301.21 (CTL5); also elsewhere on the board
/Cypress FX3/USB_CTL6: J301.19 (CTL6); also elsewhere on the board
/Cypress FX3/USB_CTL7: J301.17 (CTL7); also elsewhere on the board
/Cypress FX3/USB_CTL8: J301.15 (CTL8); also elsewhere on the board
/Cypress FX3/USB_CTL9: J301.13 (CTL9); also elsewhere on the board
/Cypress FX3/USB_CTL10: J301.11 (CTL10); also elsewhere on the board
/Cypress FX3/USB_CTL11: J301.9 (CTL11); also elsewhere on the board
/Cypress FX3/USB_CTL12: J301.7 (CTL12); also elsewhere on the board
/Cypress FX3/USB_DATA0: J301.38 (DQ0); also elsewhere on the board
/Cypress FX3/USB_DATA1: J301.36 (DQ1); also elsewhere on the board
/Cypress FX3/USB_DATA2: J301.34 (DQ2); also elsewhere on the board
/Cypress FX3/USB_DATA3: J301.32 (DQ3); also elsewhere on the board
/Cypress FX3/USB_DATA4: J301.30 (DQ4); also elsewhere on the board
/Cypress FX3/USB_DATA5: J301.28 (DQ5); also elsewhere on the board
/Cypress FX3/USB_DATA6: J301.26 (DQ6); also elsewhere on the board
/Cypress FX3/USB_DATA7: J301.24 (DQ7); also elsewhere on the board
/Cypress FX3/USB_DATA8: J301.22 (DQ8); also elsewhere on the board
/Cypress FX3/USB_DATA9: J301.20 (DQ9); also elsewhere on the board
/Cypress FX3/USB_DATA10: J301.18 (DQ10); also elsewhere on the board
/Cypress FX3/USB_DATA11: J301.16 (DQ11); also elsewhere on the board
/Cypress FX3/USB_DATA12: J301.14 (DQ12); also elsewhere on the board
/Cypress FX3/USB_DATA13: J301.12 (DQ13); also elsewhere on the board
/Cypress FX3/USB_DATA14: J301.10 (DQ14); also elsewhere on the board
/Cypress FX3/USB_DATA15: J301.8 (DQ15); also elsewhere on the board
/Cypress FX3/USB_DATA16: J302.38 (DQ16); also elsewhere on the board
/Cypress FX3/USB_DATA17: J302.36 (DQ17); also elsewhere on the board
/Cypress FX3/USB_DATA18: J302.34 (DQ18); also elsewhere on the board
/Cypress FX3/USB_DATA19: J302.32 (DQ19); also elsewhere on the board
/Cypress FX3/USB_DATA20: J302.30 (DQ20); also elsewhere on the board
/Cypress FX3/USB_DATA21: J302.28 (DQ21); also elsewhere on the board
/Cypress FX3/USB_DATA22: J302.26 (DQ22); also elsewhere on the board
/Cypress FX3/USB_DATA23: J302.24 (DQ23); also elsewhere on the board
/Cypress FX3/USB_DATA24: J302.22 (DQ24); also elsewhere on the board
/Cypress FX3/USB_DATA25: J302.20 (DQ25); also elsewhere on the board
/Cypress FX3/USB_DATA26: J302.18 (DQ26); also elsewhere on the board
/Cypress FX3/USB_DATA27: J302.16 (DQ27); also elsewhere on the board
/Cypress FX3/USB_DATA28: J302.12 (DQ28); also elsewhere on the board
/Cypress FX3/USB_DATA29: J302.10 (DQ29); also elsewhere on the board
/Cypress FX3/USB_DATA30: J302.8 (DQ30); also elsewhere on the board
/Cypress FX3/USB_DATA31: J302.6 (DQ31); also elsewhere on the board
/Cypress FX3/USB_PCLK: J301.35 (PCLK); also elsewhere on the board
GND: J301.6 (GND), J301.33 (GND), J301.37 (GND), J302.13 (GND), J302.15 (GND), J302.17 (GND), J302.25 (GND), J302.29 (GND), J302.39 (GND), J302.40 (GND); also elsewhere on the board

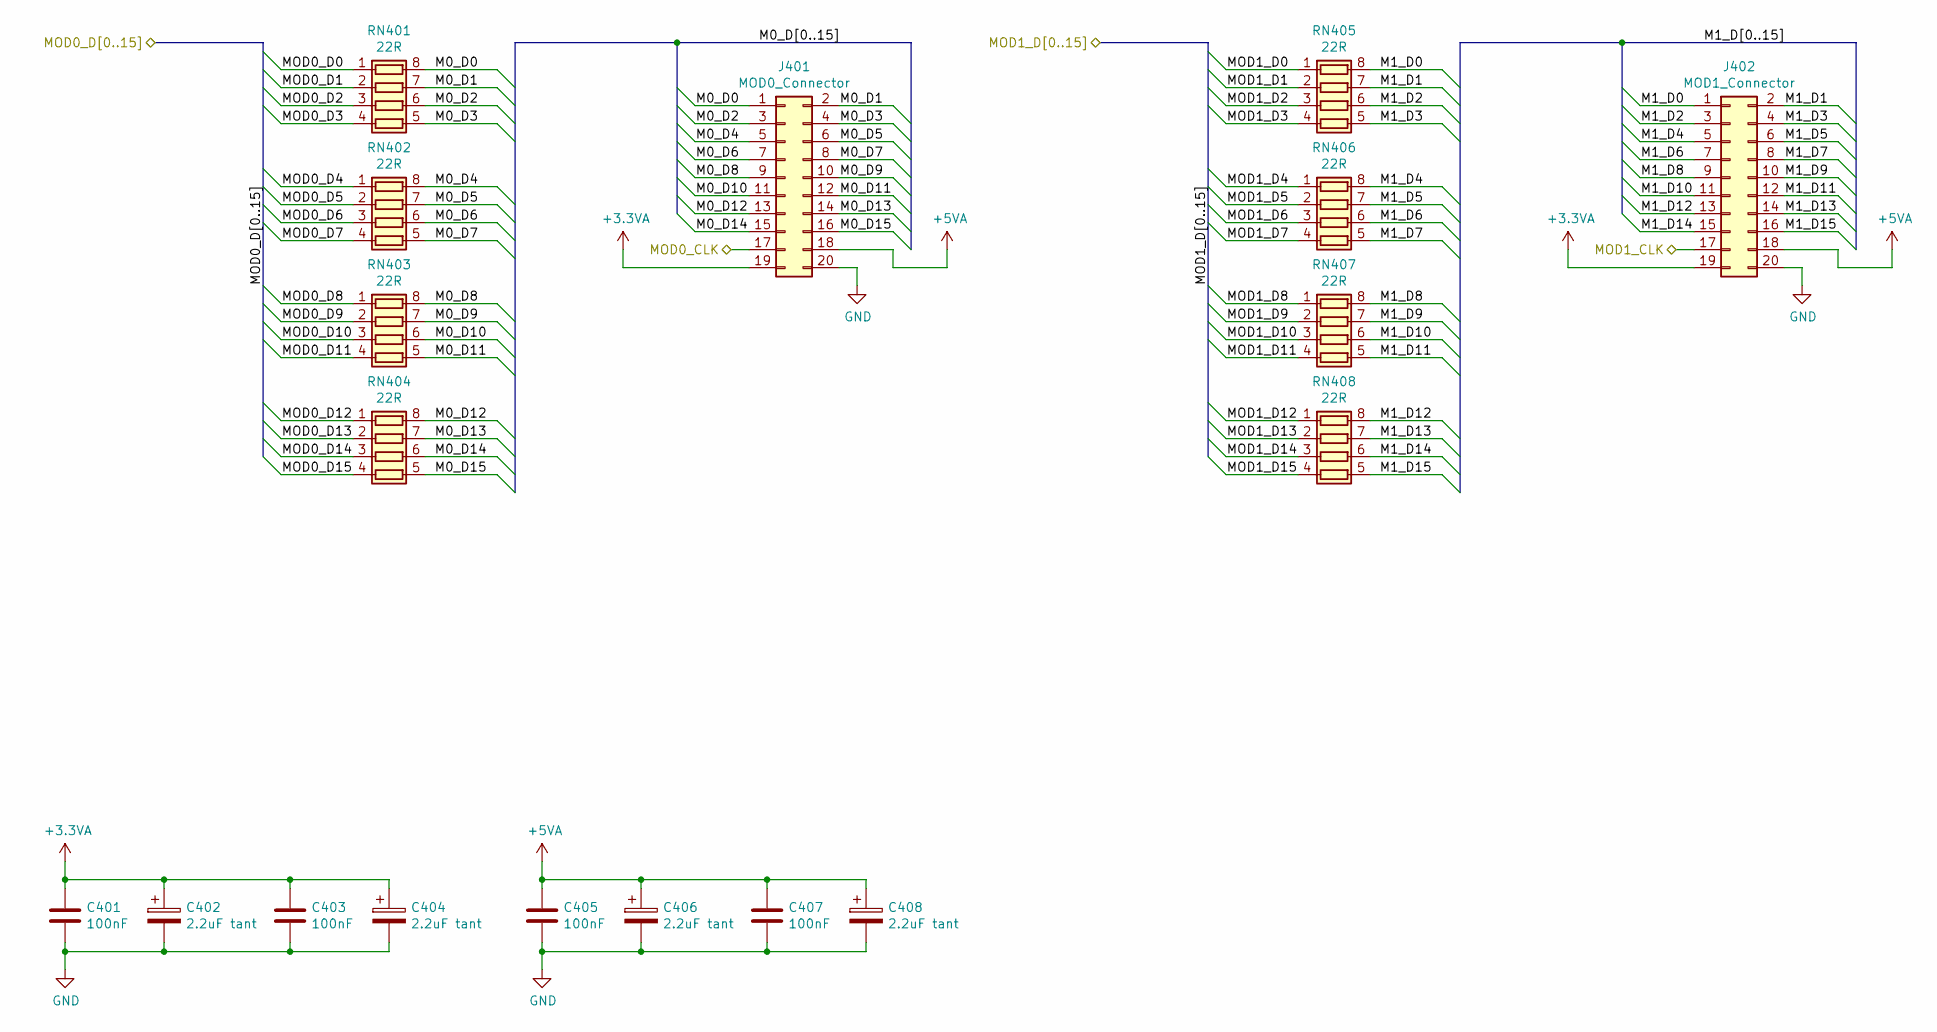
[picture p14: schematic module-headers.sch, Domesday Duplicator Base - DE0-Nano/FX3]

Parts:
C401, C403, C405, C407: 100nF; C_0805_2012Metric
C402, C404, C406, C408: 2.2uF tant; CP_EIA-3216-18_Kemet-A
J401: MOD0_Connector; IDC-Header_2x10_P2.54mm_Vertical
J402: MOD1_Connector; IDC-Header_2x10_P2.54mm_Vertical
RN401, RN402, RN403, RN404, RN405, RN406, RN407, RN408: 22R; R_Array_Convex_4x1206

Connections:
+3.3VA: C401.1, C402.1, C403.1, C404.1, J401.19, J402.19; also elsewhere on the board
+5VA: C405.1, C406.1, C407.1, C408.1, J401.18, J402.18; also elsewhere on the board
/DE0-Nano/MOD0_CLK: J401.17; also elsewhere on the board
/DE0-Nano/MOD0_D0: RN401.1 (R1.1); also elsewhere on the board
/DE0-Nano/MOD0_D1: RN401.2 (R2.1); also elsewhere on the board
/DE0-Nano/MOD0_D2: RN401.3 (R3.1); also elsewhere on the board
/DE0-Nano/MOD0_D3: RN401.4 (R4.1); also elsewhere on the board
/DE0-Nano/MOD0_D4: RN402.1 (R1.1); also elsewhere on the board
/DE0-Nano/MOD0_D5: RN402.2 (R2.1); also elsewhere on the board
/DE0-Nano/MOD0_D6: RN402.3 (R3.1); also elsewhere on the board
/DE0-Nano/MOD0_D7: RN402.4 (R4.1); also elsewhere on the board
/DE0-Nano/MOD0_D8: RN403.1 (R1.1); also elsewhere on the board
/DE0-Nano/MOD0_D9: RN403.2 (R2.1); also elsewhere on the board
/DE0-Nano/MOD0_D10: RN403.3 (R3.1); also elsewhere on the board
/DE0-Nano/MOD0_D11: RN403.4 (R4.1); also elsewhere on the board
/DE0-Nano/MOD0_D12: RN404.1 (R1.1); also elsewhere on the board
/DE0-Nano/MOD0_D13: RN404.2 (R2.1); also elsewhere on the board
/DE0-Nano/MOD0_D14: RN404.3 (R3.1); also elsewhere on the board
/DE0-Nano/MOD0_D15: RN404.4 (R4.1); also elsewhere on the board
/DE0-Nano/MOD1_CLK: J402.17; also elsewhere on the board
/DE0-Nano/MOD1_D0: RN405.1 (R1.1); also elsewhere on the board
/DE0-Nano/MOD1_D1: RN405.2 (R2.1); also elsewhere on the board
/DE0-Nano/MOD1_D2: RN405.3 (R3.1); also elsewhere on the board
/DE0-Nano/MOD1_D3: RN405.4 (R4.1); also elsewhere on the board
/DE0-Nano/MOD1_D4: RN406.1 (R1.1); also elsewhere on the board
/DE0-Nano/MOD1_D5: RN406.2 (R2.1); also elsewhere on the board
/DE0-Nano/MOD1_D6: RN406.3 (R3.1); also elsewhere on the board
/DE0-Nano/MOD1_D7: RN406.4 (R4.1); also elsewhere on the board
/DE0-Nano/MOD1_D8: RN407.1 (R1.1); also elsewhere on the board
/DE0-Nano/MOD1_D9: RN407.2 (R2.1); also elsewhere on the board
/DE0-Nano/MOD1_D10: RN407.3 (R3.1); also elsewhere on the board
/DE0-Nano/MOD1_D11: RN407.4 (R4.1); also elsewhere on the board
/DE0-Nano/MOD1_D12: RN408.1 (R1.1); also elsewhere on the board
/DE0-Nano/MOD1_D13: RN408.2 (R2.1); also elsewhere on the board
/DE0-Nano/MOD1_D14: RN408.3 (R3.1); also elsewhere on the board
/DE0-Nano/MOD1_D15: RN408.4 (R4.1); also elsewhere on the board
/Module Headers/M0_D0: J401.1, RN401.8 (R1.2)
/Module Headers/M0_D1: J401.2, RN401.7 (R2.2)
/Module Headers/M0_D2: J401.3, RN401.6 (R3.2)
/Module Headers/M0_D3: J401.4, RN401.5 (R4.2)
/Module Headers/M0_D4: J401.5, RN402.8 (R1.2)
/Module Headers/M0_D5: J401.6, RN402.7 (R2.2)
/Module Headers/M0_D6: J401.7, RN402.6 (R3.2)
/Module Headers/M0_D7: J401.8, RN402.5 (R4.2)
/Module Headers/M0_D8: J401.9, RN403.8 (R1.2)
/Module Headers/M0_D9: J401.10, RN403.7 (R2.2)
/Module Headers/M0_D10: J401.11, RN403.6 (R3.2)
/Module Headers/M0_D11: J401.12, RN403.5 (R4.2)
/Module Headers/M0_D12: J401.13, RN404.8 (R1.2)
/Module Headers/M0_D13: J401.14, RN404.7 (R2.2)
/Module Headers/M0_D14: J401.15, RN404.6 (R3.2)
/Module Headers/M0_D15: J401.16, RN404.5 (R4.2)
/Module Headers/M1_D0: J402.1, RN405.8 (R1.2)
/Module Headers/M1_D1: J402.2, RN405.7 (R2.2)
/Module Headers/M1_D2: J402.3, RN405.6 (R3.2)
/Module Headers/M1_D3: J402.4, RN405.5 (R4.2)
/Module Headers/M1_D4: J402.5, RN406.8 (R1.2)
/Module Headers/M1_D5: J402.6, RN406.7 (R2.2)
/Module Headers/M1_D6: J402.7, RN406.6 (R3.2)
/Module Headers/M1_D7: J402.8, RN406.5 (R4.2)
/Module Headers/M1_D8: J402.9, RN407.8 (R1.2)
/Module Headers/M1_D9: J402.10, RN407.7 (R2.2)
/Module Headers/M1_D10: J402.11, RN407.6 (R3.2)
/Module Headers/M1_D11: J402.12, RN407.5 (R4.2)
/Module Headers/M1_D12: J402.13, RN408.8 (R1.2)
/Module Headers/M1_D13: J402.14, RN408.7 (R2.2)
/Module Headers/M1_D14: J402.15, RN408.6 (R3.2)
/Module Headers/M1_D15: J402.16, RN408.5 (R4.2)
GND: C401.2, C402.2, C403.2, C404.2, C405.2, C406.2, C407.2, C408.2, J401.20, J402.20; also elsewhere on the board

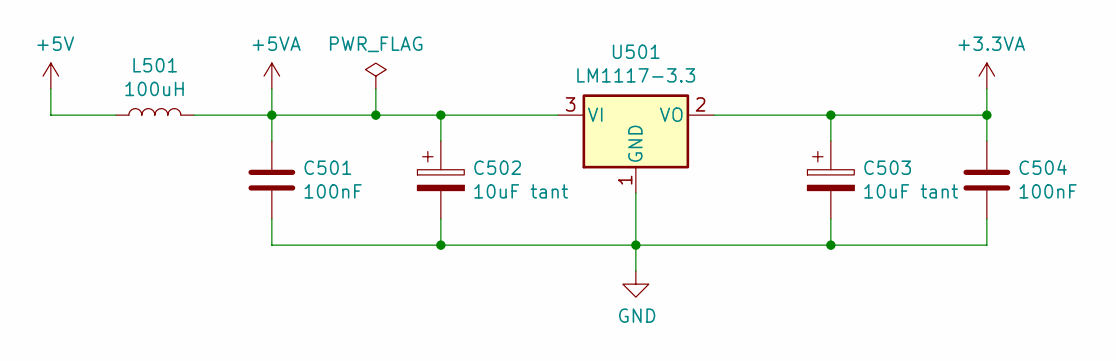
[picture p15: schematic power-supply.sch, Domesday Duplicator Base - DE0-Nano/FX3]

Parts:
C501, C504: 100nF; C_0805_2012Metric
C502, C503: 10uF tant; CP_EIA-3528-21_Kemet-B
L501: 100uH; L_Bourns_SRN8040TA
U501: LM1117-3.3; SOT-223-3_TabPin2

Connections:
+3.3VA: C503.1, C504.1, U501.2 (VO); also elsewhere on the board
+5V: L501.1; also elsewhere on the board
+5VA: C501.1, C502.1, L501.2, U501.3 (VI); also elsewhere on the board
GND: C501.2, C502.2, C503.2, C504.2, U501.1 (GND); also elsewhere on the board

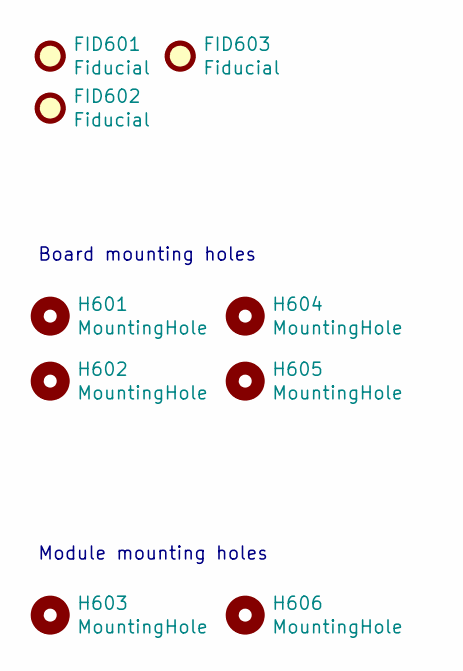
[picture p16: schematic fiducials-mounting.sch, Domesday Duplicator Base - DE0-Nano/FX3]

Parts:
FID601, FID602, FID603: Fiducial; Fiducial_0.5mm_Dia_1mm_Outer
H601, H602, H604, H605: MountingHole; MountingHole_3.2mm_M3
H603, H606: MountingHole; MountingHole_2.2mm_M2

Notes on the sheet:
Module mounting holes
Board mounting holes



Board: 2 copper layers, 99.1 x 90.8 mm, 38 parts (2 on the bottom side), 116 nets.

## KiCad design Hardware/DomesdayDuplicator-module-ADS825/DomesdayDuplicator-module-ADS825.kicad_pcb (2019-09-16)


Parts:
C201, C202, C203: 100nF; C_0805_2012Metric
C204: 2.2uF Tant; CP_EIA-3216-18_Kemet-A
C205: 330pF; C_0805_2012Metric
C206: 33pF; C_0805_2012Metric
C207: 470pF; C_0805_2012Metric
C208: 100pF; C_0805_2012Metric
C209: 270pF; C_0805_2012Metric
J201: RF_In_50R; RF_SMA_RightAngle_5-1814400-1
L201: 680uH; L_0805_2012Metric
L202: 560uH; L_0805_2012Metric
R201: 56R; R_0805_2012Metric
R202: 200R; R_0805_2012Metric
R203: 100R; R_0805_2012Metric
R204: 1K5; R_0805_2012Metric
R205: 1K; R_0805_2012Metric
R206: 680R; R_0805_2012Metric
R207: 560R; R_0805_2012Metric
R208, R209: 47R; R_0805_2012Metric
SW201: Gain_Select; SW_DIP_SPSTx04_Slide_Copal_CHS-04B_W7.62mm_P1.27mm
U201: OPA690IDBVT; SOT-23-6

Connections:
+5VA: C203.2, C204.1, U201.5 (ENABLE), U201.6 (V+); also elsewhere on the board
/ADC/ANALOG_IN: R209.1; also elsewhere on the board
/ADC/DC_OFFSET: C201.1, R203.2; also elsewhere on the board
GND: C202.1, C203.1, C204.2, C205.1, C207.1, C209.1, J201.2 (Ext), R201.2, U201.2 (V-); also elsewhere on the board
unnamed: C201.2, J201.1 (In), R201.1
unnamed: C202.2, R202.1
unnamed: C205.2, C206.2, L201.1, R208.1
unnamed: C206.1, C207.2, C208.2, L201.2, L202.1
unnamed: C208.1, C209.2, L202.2, R209.2
unnamed: R202.2, R204.2, R205.2, R206.2, R207.2, U201.4 (-)
unnamed: R203.1, U201.3 (+)
unnamed: R204.1, SW201.1
unnamed: R205.1, SW201.2
unnamed: R206.1, SW201.3
unnamed: R207.1, SW201.4
unnamed: R208.2, SW201.5, SW201.6, SW201.7, SW201.8, U201.1

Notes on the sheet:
2N Elliptic Filter (14 MHz low-pass)
Filter capactors should be 5% tolerance
Note: The cable terminating resistor should take into account the parallel resistance of the dividing network: 1000 / 2 = 500 Ohms Rtotal = R1 x R2 / (R1 + R2) (500 * 56) / (500 + 56) = 50.36 Ohms


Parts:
C301, C303, C305, C307, C308, C311, C313, C315: 100nF; C_0805_2012Metric
C302, C304, C306, C309, C310, C312, C314, C316: 2.2uF Tant; CP_EIA-3216-18_Kemet-A
R301, R302: 1K; R_0805_2012Metric
U301: MCP602; SOIC-8_3.9x4.9mm_P1.27mm
U302: ADS825E; SSOP-28_5.3x10.2mm_P0.65mm

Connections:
+3V3: C307.1, C309.1, U302.17 (RSEL), U302.28 (VDRV); also elsewhere on the board
+5VA: C301.1, C302.1, C303.1, C304.1, U301.8 (V+), U302.15 (+Vs), U302.27 (+Vs); also elsewhere on the board
/ADC/ANALOG_IN: U302.25 (IN); also elsewhere on the board
/ADC/CLK: U302.14 (CLK); also elsewhere on the board
/ADC/DC_OFFSET: U301.1, U301.2 (-); also elsewhere on the board
/ADC/DO0: U302.11 (D0); also elsewhere on the board
/ADC/DO1: U302.10 (D1); also elsewhere on the board
/ADC/DO2: U302.9 (D2); also elsewhere on the board
/ADC/DO3: U302.8 (D3); also elsewhere on the board
/ADC/DO4: U302.7 (D4); also elsewhere on the board
/ADC/DO5: U302.6 (D5); also elsewhere on the board
/ADC/DO6: U302.5 (D6); also elsewhere on the board
/ADC/DO7: U302.4 (D7); also elsewhere on the board
/ADC/DO8: U302.3 (D8); also elsewhere on the board
/ADC/DO9: U302.2 (D9); also elsewhere on the board
GND: C301.2, C302.2, C303.2, C304.2, C305.2, C306.2, C307.2, C308.2, C309.2, C310.2, C311.2, C312.2, C313.2, C314.2, C315.2, C316.2, U301.4 (V-), U302.1 (GND), U302.12 (~OE), U302.13 (PD), U302.16 (GND), U302.18 (~INT/EXT), U302.26 (AGND); also elsewhere on the board
unnamed: C305.1, C306.1, R301.1, U302.22 (REFT)
unnamed: C308.1, C310.1, R302.1, U302.19 (REFB)
unnamed: C311.1, C312.1, U302.21 (ByT)
unnamed: C313.1, C314.1, U302.20 (ByB)
unnamed: C315.1, C316.1, U302.23 (CM)
unnamed: R301.2, R302.2, U301.3 (+), U301.5 (+)
unnamed: U301.6 (-), U301.7, U302.24 (~IN)


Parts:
C401, C402: 100nF; C_0805_2012Metric
U401, U402: 74LVTH541; SSOP-20_4.4x6.5mm_P0.65mm

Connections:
+3V3: C401.1, C402.1, U401.20 (VCC), U402.20 (VCC); also elsewhere on the board
/ADC/DO0: U401.2 (A0); also elsewhere on the board
/ADC/DO1: U401.3 (A1); also elsewhere on the board
/ADC/DO2: U401.4 (A2); also elsewhere on the board
/ADC/DO3: U401.5 (A3); also elsewhere on the board
/ADC/DO4: U401.6 (A4); also elsewhere on the board
/ADC/DO5: U401.7 (A5); also elsewhere on the board
/ADC/DO6: U401.8 (A6); also elsewhere on the board
/ADC/DO7: U401.9 (A7); also elsewhere on the board
/ADC/DO8: U402.2 (A0); also elsewhere on the board
/ADC/DO9: U402.3 (A1); also elsewhere on the board
/Header/DB0: U401.18 (Y0); also elsewhere on the board
/Header/DB1: U401.17 (Y1); also elsewhere on the board
/Header/DB2: U401.16 (Y2); also elsewhere on the board
/Header/DB3: U401.15 (Y3); also elsewhere on the board
/Header/DB4: U401.14 (Y4); also elsewhere on the board
/Header/DB5: U401.13 (Y5); also elsewhere on the board
/Header/DB6: U401.12 (Y6); also elsewhere on the board
/Header/DB7: U401.11 (Y7); also elsewhere on the board
/Header/DB8: U402.18 (Y0); also elsewhere on the board
/Header/DB9: U402.17 (Y1); also elsewhere on the board
/Header/DB10: U402.16 (Y2); also elsewhere on the board
/Line Drivers/TRIGGER_IN: U402.4 (A2); also elsewhere on the board
GND: C401.2, C402.2, U401.1 (G1), U401.10 (GND), U401.19 (G2), U402.1 (G1), U402.5 (A3), U402.6 (A4), U402.7 (A5), U402.8 (A6), U402.9 (A7), U402.10 (GND), U402.19 (G2); also elsewhere on the board


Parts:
C501: 100nF; C_0805_2012Metric
C502: 2.2uF Tant; CP_EIA-3216-18_Kemet-A
J501: Trigger_In_50R; RF_SMA_RightAngle_5-1814400-1
R501, R502: 47R; R_0805_2012Metric
R503: 10K; R_0805_2012Metric
RV501: 10K; Potentiometer_Bourns_3314G_Vertical
U501: TLV3501; SOT-23-6

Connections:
+5VA: C501.1, C502.1, RV501.1, U501.4 (V+); also elsewhere on the board
/Line Drivers/TRIGGER_IN: R503.2, U501.5; also elsewhere on the board
GND: C501.2, C502.2, J501.2 (Ext), RV501.3, U501.2 (V-), U501.6 (SHDN); also elsewhere on the board
unnamed: J501.1 (In), R501.2
unnamed: R501.1, U501.1 (-)
unnamed: R502.1, RV501.2
unnamed: R502.2, R503.1, U501.3 (+)

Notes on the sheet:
Note: The potentiometer sets the Vref trigger point between +5V and 0V

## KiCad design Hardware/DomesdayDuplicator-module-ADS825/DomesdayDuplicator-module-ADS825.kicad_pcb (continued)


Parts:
J601: Module_Connector; PinSocket_2x10_P2.54mm_Vertical

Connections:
+3V3: J601.19; also elsewhere on the board
+5VA: J601.18; also elsewhere on the board
/ADC/CLK: J601.17; also elsewhere on the board
/Header/DB0: J601.1; also elsewhere on the board
/Header/DB1: J601.2; also elsewhere on the board
/Header/DB2: J601.3; also elsewhere on the board
/Header/DB3: J601.4; also elsewhere on the board
/Header/DB4: J601.5; also elsewhere on the board
/Header/DB5: J601.6; also elsewhere on the board
/Header/DB6: J601.7; also elsewhere on the board
/Header/DB7: J601.8; also elsewhere on the board
/Header/DB8: J601.9; also elsewhere on the board
/Header/DB9: J601.10; also elsewhere on the board
/Header/DB10: J601.11; also elsewhere on the board
GND: J601.20; also elsewhere on the board


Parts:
FID701, FID702, FID703: Fiducial; Fiducial_0.5mm_Dia_1mm_Outer
H701: MountingHole; MountingHole_2.2mm_M2


Board: 2 copper layers, 49.5 x 38.1 mm, 60 parts (1 on the bottom side), 51 nets.

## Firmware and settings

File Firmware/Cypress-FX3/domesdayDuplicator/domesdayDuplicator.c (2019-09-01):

/************************************************************************

	domesdayDuplicator.c

	FX3 Firmware main functions
	DomesdayDuplicator - LaserDisc RF sampler
	Copyright (C) 2018 Simon Inns

	This file is part of Domesday Duplicator.

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
	Email: simon.inns@gmail.com

************************************************************************/

// External includes
#include "cyu3system.h"
#include "cyu3os.h"
#include "cyu3dma.h"
#include "cyu3error.h"
#include "cyu3usb.h"
#include "cyu3uart.h"
#include "cyu3gpio.h"
#include "cyu3utils.h"
#include "cyu3pib.h"
#include "cyu3gpif.h"

// Local includes
#include "domesdayDuplicator.h"
#include "domesdayDuplicatorGpif.h"

// Global definitions
CyU3PThread glAppThread; // Application thread structure
CyU3PDmaMultiChannel glDmaMultiChHandle; // DMA multi-channel handle

CyBool_t glIsApplnActive = CyFalse; // Application active/ready flag
CyBool_t glForceLinkU2 = CyFalse; // Force U2 flag

volatile CyBool_t input0Flag = CyFalse; // Input 0 set flag
volatile CyBool_t input1Flag = CyFalse; // Input 1 set flag
volatile CyBool_t input2Flag = CyFalse; // Input 2 set flag
volatile CyBool_t input3Flag = CyFalse; // Input 3 set flag

CyBool_t input0HandledFlag = CyFalse; // Input 0 set condition handled flag
CyBool_t input1HandledFlag = CyFalse; // Input 1 set condition handled flag
CyBool_t input2HandledFlag = CyFalse; // Input 2 set condition handled flag
CyBool_t input3HandledFlag = CyFalse; // Input 3 set condition handled flag

volatile CyBool_t dataCollectionFlag = CyFalse; // Flag to show if the host application is collecting data

// Main application function
int main(void)
{
    CyU3PIoMatrixConfig_t io_cfg;
    CyU3PPibClock_t pibClock;
    CyU3PGpioClock_t gpioClock;
    CyU3PGpioSimpleConfig_t gpioConfig;
    CyU3PReturnStatus_t status = CY_U3P_SUCCESS;

    // Perform initial clock configuration of the FX3
    CyU3PSysClockConfig_t clockConfig;
    clockConfig.setSysClk400  = CyTrue; // True = 403.2 MHz, false = 384 MHz
    clockConfig.cpuClkDiv     = 2;
    clockConfig.dmaClkDiv     = 2;
    clockConfig.mmioClkDiv    = 2;
    clockConfig.useStandbyClk = CyFalse;
    clockConfig.clkSrc        = CY_U3P_SYS_CLK;
    status = CyU3PDeviceInit(&clockConfig);
    if (status != CY_U3P_SUCCESS) {
        goto handleFatalError;
    }

    // Initialise the state of the caches - Icache, Dcache, DMAcache
    status = CyU3PDeviceCacheControl(CyTrue, CyFalse, CyFalse);
    if (status != CY_U3P_SUCCESS) {
        goto handleFatalError;
    }

    // Initialise the IO matrix
    io_cfg.isDQ32Bit = CyFalse; // Data bus is 16-bits
    io_cfg.useUart   = CyTrue;
    io_cfg.useI2C    = CyFalse;
    io_cfg.useI2S    = CyFalse;
    io_cfg.useSpi    = CyFalse;
    io_cfg.lppMode   = CY_U3P_IO_MATRIX_LPP_UART_ONLY; // 16-bit data bus with UART

    // Note:
    // If io_cfg.isDQ32Bit = CyFalse then GPIO[0:15] and CTL[0:4] will be reserved for GPIF
    io_cfg.gpioSimpleEn[0] = 0;	// Most significant GPIOs 32-63
    io_cfg.gpioSimpleEn[1] = 0; // Least significant GPIOs 0-31
    io_cfg.gpioComplexEn[0] = 0;
    io_cfg.gpioComplexEn[1] = 0;

    status = CyU3PDeviceConfigureIOMatrix(&io_cfg);
    if (status != CY_U3P_SUCCESS) {
        goto handleFatalError;
    }

    // Start GPIF clocks, they need to be running before we attach a DMA channel to GPIF
	pibClock.clkDiv = 4; // 403.2 / 4 = 100.8 MHz
	pibClock.clkSrc = CY_U3P_SYS_CLK;
	pibClock.isHalfDiv = CyFalse;
	pibClock.isDllEnable = CyFalse; // Disable Dll (not required for synchronous applications)
	status = CyU3PPibInit(CyTrue, &pibClock);
	if (status != CY_U3P_SUCCESS) {
		goto handleFatalError;
	}

    // Initialise the GPIO module clocks, needed for nRESET towards FPGA
	gpioClock.fastClkDiv = 2;
	gpioClock.slowClkDiv = 0;
	gpioClock.simpleDiv = CY_U3P_GPIO_SIMPLE_DIV_BY_2;
	gpioClock.clkSrc = CY_U3P_SYS_CLK;
	gpioClock.halfDiv = 0;

	// Initialise the GPIO and set the callback function (for GPIO interrupts)
	status = CyU3PGpioInit(&gpioClock, gpioInterruptCallback);
	if (status != CY_U3P_SUCCESS) {
		goto handleFatalError;
	}

	// Claim GPIO19 from the GPIF Interface (collectData signal)
	status = CyU3PDeviceGpioOverride(19, CyTrue);
	if (status != CY_U3P_SUCCESS) {
		goto handleFatalError;
	}

	// Put the FPGA in not collectData by driving GPIO19 low
	CyU3PMemSet((uint8_t *)&gpioConfig, 0, sizeof(gpioConfig));
	gpioConfig.outValue = CyFalse;
	gpioConfig.driveLowEn = CyTrue;
	gpioConfig.driveHighEn = CyTrue;
	status = CyU3PGpioSetSimpleConfig(19, &gpioConfig);
	if (status != CY_U3P_SUCCESS) {
		goto handleFatalError;
	}

	// Claim GPIO27 from the GPIF Interface (nRESET signal)
	status = CyU3PDeviceGpioOverride(27, CyTrue);
	if (status != CY_U3P_SUCCESS) {
		goto handleFatalError;
	}

	// Bring the FPGA out of reset by driving nRESET/GPIO27 high
	CyU3PMemSet((uint8_t *)&gpioConfig, 0, sizeof(gpioConfig));
	gpioConfig.outValue = CyTrue;
	gpioConfig.driveLowEn = CyTrue;
	gpioConfig.driveHighEn = CyTrue;
	status = CyU3PGpioSetSimpleConfig(27, &gpioConfig);
	if (status != CY_U3P_SUCCESS) {
		goto handleFatalError;
	}

	// Generic input signals from FPGA (GPIO 20, 21, 28 and 29) -------------------------------------------------------

	// Claim GPIO20 from the GPIF Interface (input0)
	status = CyU3PDeviceGpioOverride(20, CyTrue);
	if (status != CY_U3P_SUCCESS) {
		goto handleFatalError;
	}

	// Configure as input
	CyU3PMemSet((uint8_t *)&gpioConfig, 0, sizeof(gpioConfig));
	gpioConfig.outValue = CyTrue;
	gpioConfig.driveLowEn = CyFalse;
	gpioConfig.driveHighEn = CyFalse;
	gpioConfig.inputEn = CyTrue;
	gpioConfig.intrMode = CY_U3P_GPIO_INTR_POS_EDGE;

	status = CyU3PGpioSetSimpleConfig(20, &gpioConfig);
	if (status != CY_U3P_SUCCESS) {
		goto handleFatalError;
	}

	// Claim GPIO21 from the GPIF Interface (input1)
	status = CyU3PDeviceGpioOverride(21, CyTrue);
	if (status != CY_U3P_SUCCESS) {
		goto handleFatalError;
	}

	// Configure as input
	CyU3PMemSet((uint8_t *)&gpioConfig, 0, sizeof(gpioConfig));
	gpioConfig.outValue = CyTrue;
	gpioConfig.driveLowEn = CyFalse;
	gpioConfig.driveHighEn = CyFalse;
	gpioConfig.inputEn = CyTrue;
	gpioConfig.intrMode = CY_U3P_GPIO_INTR_POS_EDGE;

	status = CyU3PGpioSetSimpleConfig(21, &gpioConfig);
	if (status != CY_U3P_SUCCESS) {
		goto handleFatalError;
	}

	// Claim GPIO28 from the GPIF Interface (input2)
	status = CyU3PDeviceGpioOverride(28, CyTrue);
	if (status != CY_U3P_SUCCESS) {
		goto handleFatalError;
	}

	// Configure as input
	CyU3PMemSet((uint8_t *)&gpioConfig, 0, sizeof(gpioConfig));
	gpioConfig.outValue = CyTrue;
	gpioConfig.driveLowEn = CyFalse;
	gpioConfig.driveHighEn = CyFalse;
	gpioConfig.inputEn = CyTrue;
	gpioConfig.intrMode = CY_U3P_GPIO_INTR_POS_EDGE;

	status = CyU3PGpioSetSimpleConfig(28, &gpioConfig);
	if (status != CY_U3P_SUCCESS) {
		goto handleFatalError;
	}

	// Claim GPIO29 from the GPIF Interface (input3)
	status = CyU3PDeviceGpioOverride(29, CyTrue);
	if (status != CY_U3P_SUCCESS) {
		goto handleFatalError;
	}

	// Configure as input
	CyU3PMemSet((uint8_t *)&gpioConfig, 0, sizeof(gpioConfig));
	gpioConfig.outValue = CyTrue;
	gpioConfig.driveLowEn = CyFalse;
	gpioConfig.driveHighEn = CyFalse;
	gpioConfig.inputEn = CyTrue;
	gpioConfig.intrMode = CY_U3P_GPIO_INTR_POS_EDGE;

	status = CyU3PGpioSetSimpleConfig(29, &gpioConfig);
	if (status != CY_U3P_SUCCESS) {
		goto handleFatalError;
	}

	// Generic output signals to FPGA (GPIO 22 (early), 23 (delayed), -------------------------------------------------
	// 24 (delayed), 25 (delayed), 26 (delayed))

	// Claim GPIO22 from the GPIF Interface (outputE0)
	status = CyU3PDeviceGpioOverride(22, CyTrue);
	if (status != CY_U3P_SUCCESS) {
		goto handleFatalError;
	}

	// Drive pin low
	CyU3PMemSet((uint8_t *)&gpioConfig, 0, sizeof(gpioConfig));
	gpioConfig.outValue = CyFalse;
	gpioConfig.driveLowEn = CyTrue;
	gpioConfig.driveHighEn = CyTrue;
	status = CyU3PGpioSetSimpleConfig(22, &gpioConfig);
	if (status != CY_U3P_SUCCESS) {
		goto handleFatalError;
	}

	// Claim GPIO23 from the GPIF Interface (outputD0)
	status = CyU3PDeviceGpioOverride(23, CyTrue);
	if (status != CY_U3P_SUCCESS) {
		goto handleFatalError;
	}

	// Drive pin low
	CyU3PMemSet((uint8_t *)&gpioConfig, 0, sizeof(gpioConfig));
	gpioConfig.outValue = CyFalse;
	gpioConfig.driveLowEn = CyTrue;
	gpioConfig.driveHighEn = CyTrue;
	status = CyU3PGpioSetSimpleConfig(23, &gpioConfig);
	if (status != CY_U3P_SUCCESS) {
		goto handleFatalError;
	}

	// Claim GPIO24 from the GPIF Interface (outputD1)
	status = CyU3PDeviceGpioOverride(24, CyTrue);
	if (status != CY_U3P_SUCCESS) {
		goto handleFatalError;
	}

	// Drive pin low
	CyU3PMemSet((uint8_t *)&gpioConfig, 0, sizeof(gpioConfig));
	gpioConfig.outValue = CyFalse;
	gpioConfig.driveLowEn = CyTrue;
	gpioConfig.driveHighEn = CyTrue;
	status = CyU3PGpioSetSimpleConfig(24, &gpioConfig);
	if (status != CY_U3P_SUCCESS) {
		goto handleFatalError;
	}

	// Claim GPIO25 from the GPIF Interface (outputD2)
	status = CyU3PDeviceGpioOverride(25, CyTrue);
	if (status != CY_U3P_SUCCESS) {
		goto handleFatalError;
	}

	// Drive pin low
	CyU3PMemSet((uint8_t *)&gpioConfig, 0, sizeof(gpioConfig));
	gpioConfig.outValue = CyFalse;
	gpioConfig.driveLowEn = CyTrue;
	gpioConfig.driveHighEn = CyTrue;
	status = CyU3PGpioSetSimpleConfig(25, &gpioConfig);
	if (status != CY_U3P_SUCCESS) {
		goto handleFatalError;
	}

	// Claim GPIO26 from the GPIF Interface (outputD3)
	status = CyU3PDeviceGpioOverride(26, CyTrue);
	if (status != CY_U3P_SUCCESS) {
		goto handleFatalError;
	}

	// Drive pin low
	CyU3PMemSet((uint8_t *)&gpioConfig, 0, sizeof(gpioConfig));
	gpioConfig.outValue = CyFalse;
	gpioConfig.driveLowEn = CyTrue;
	gpioConfig.driveHighEn = CyTrue;
	status = CyU3PGpioSetSimpleConfig(26, &gpioConfig);
	if (status != CY_U3P_SUCCESS) {
		goto handleFatalError;
	}

    // Initialise the RTOS kernel -------------------------------------------------------------------------------------
    CyU3PKernelEntry();

    return 0;

handleFatalError:

    // An unrecoverable error has occurred
	// Loop forever
	while(1);
}

// Function to initialise the application's main thread
void domDupThreadInitialise(uint32_t input)
{
    CyU3PReturnStatus_t status;
    CyU3PUsbLinkPowerMode powerState;

    // Initialise the debug console
    domDupDebugInit();
    CyU3PDebugPrint(1, "\r\nDomesday Duplicator FX3 Firmware - Build 0062\r\n");
    CyU3PDebugPrint(1, "(c)2018 Simon Inns - https://www.domesday86.com\r\n\r\n");
    CyU3PDebugPrint(1, "domDupThreadInitialise(): Debug console initialised\r\n");

    // Initialise the application
    domDupInitialiseApplication();

    // Main application thread loop
    while(1) {
        // Try to get the USB 3.0 link back to U0
        if (glForceLinkU2) {
        	status = CyU3PUsbGetLinkPowerState(&powerState);
            while ((glForceLinkU2) && (status == CY_U3P_SUCCESS) && (powerState == CyU3PUsbLPM_U0)) {
                // Try to get to U2 state
                CyU3PUsbSetLinkPowerState(CyU3PUsbLPM_U2);
                CyU3PThreadSleep(5);
                status = CyU3PUsbGetLinkPowerState(&powerState);
            }
        } else {
            // Try to get the USB link back to U0
            if (CyU3PUsbGetSpeed () == CY_U3P_SUPER_SPEED) {
            	status = CyU3PUsbGetLinkPowerState (&powerState);
                while ((status == CY_U3P_SUCCESS) && (powerState >= CyU3PUsbLPM_U1) &&
                	(powerState <= CyU3PUsbLPM_U3)) {
                    CyU3PUsbSetLinkPowerState(CyU3PUsbLPM_U0);
                    CyU3PThreadSleep(1);
                    status = CyU3PUsbGetLinkPowerState(&powerState);
                }
            }
        }

        // Process the input0 flag (generated via GPIO interrupt)
        if (input0Flag) {
        	// Ensure we only output the debug once
        	if (!input0HandledFlag) {
        		input0HandledFlag = CyTrue;
        		CyU3PDebugPrint(4, "Main application loop: input0 pin set by the FPGA\r\n");
        	}
        }

        // Process the input1 flag (generated via GPIO interrupt)
		if (input1Flag) {
			// Ensure we only output the debug once
			if (!input1HandledFlag) {
				input1HandledFlag = CyTrue;
				CyU3PDebugPrint(4, "Main application loop: input1 pin set by the FPGA\r\n");
			}
		}

		// Process the input2 flag (generated via GPIO interrupt)
		if (input2Flag) {
			// Ensure we only output the debug once
			if (!input2HandledFlag) {
				input2HandledFlag = CyTrue;
				CyU3PDebugPrint(4, "Main application loop: input2 pin set by the FPGA\r\n");
			}
		}

		// Process the input3 flag (generated via GPIO interrupt)
		if (input3Flag) {
			// Ensure we only output the debug once
			if (!input3HandledFlag) {
				input3HandledFlag = CyTrue;
				CyU3PDebugPrint(4, "Main application loop: input3 pin set by the FPGA\r\n");
			}
		}
    }
}

// Function to create the initial application thread
void CyFxApplicationDefine(void)
{
    void *ptr = NULL;
    uint32_t returnCode = CY_U3P_SUCCESS;

    // Allocate the memory for the threads
    ptr = CyU3PMemAlloc(CY_FX_GPIFTOUSB_THREAD_STACK);

    // Create the application's main thread
    returnCode = CyU3PThreadCreate(
		&glAppThread,						// Application thread structure
		"28:domDup",						// Thread ID and thread name
		domDupThreadInitialise,				// Application thread entry function
		0,									// No input parameter to thread
		ptr,								// Pointer to the allocated thread stack
		CY_FX_GPIFTOUSB_THREAD_STACK,		// Application thread stack size
		CY_FX_GPIFTOUSB_THREAD_PRIORITY,	// Application thread priority
		CY_FX_GPIFTOUSB_THREAD_PRIORITY,	// Application thread priority
		CYU3P_NO_TIME_SLICE,				// No time slice for the application thread
		CYU3P_AUTO_START					// Start the thread immediately
		);

    // Check the return code
    if (returnCode != 0) {
    	// Could not create initial thread
    	// Application cannot start
        while(1);
    }
}

// Function to initialise the USB application (note: does not start application)
void domDupInitialiseApplication(void)
{
    CyU3PReturnStatus_t apiReturnStatus = CY_U3P_SUCCESS;
    CyBool_t noRenum = CyFalse;

    // Start the USB processing
    apiReturnStatus = CyU3PUsbStart();
    if (apiReturnStatus == CY_U3P_ERROR_NO_REENUM_REQUIRED) noRenum = CyTrue;
    else if (apiReturnStatus != CY_U3P_SUCCESS) {
        CyU3PDebugPrint(4, "domDupInitialiseApplication(): CyU3PUsbStart failed, Error code = %d\r\n", apiReturnStatus);
        domDupErrorHandler(apiReturnStatus);
    }

    // Use fast enumeration
    CyU3PUsbRegisterSetupCallback(domDupUSBSetupCB, CyTrue);

    // Add USB event callback function
    CyU3PUsbRegisterEventCallback(domDupUSBEventCB);

    // Add LPM request callback function
    CyU3PUsbRegisterLPMRequestCallback(domDupLPMRequestCB);

    // Set the USB descriptors

    // Super speed device descriptor (USB 3)
    apiReturnStatus = CyU3PUsbSetDesc(CY_U3P_USB_SET_SS_DEVICE_DESCR, 0, (uint8_t *)USB30DeviceDscr);
    if (apiReturnStatus != CY_U3P_SUCCESS) {
        CyU3PDebugPrint(4, "domDupInitialiseApplication(): CyU3PUsbSetDesc USB3 failed, Error code = %d\r\n", apiReturnStatus);
        domDupErrorHandler(apiReturnStatus);
    }

    // High speed device descriptor (USB 2)
    apiReturnStatus = CyU3PUsbSetDesc(CY_U3P_USB_SET_HS_DEVICE_DESCR, 0, (uint8_t *)USB20DeviceDscr);
    if (apiReturnStatus != CY_U3P_SUCCESS) {
        CyU3PDebugPrint(4, "domDupInitialiseApplication(): CyU3PUsbSetDesc USB 2 failed, Error code = %d\r\n", apiReturnStatus);
        domDupErrorHandler(apiReturnStatus);
    }

    // BOS descriptor
    apiReturnStatus = CyU3PUsbSetDesc(CY_U3P_USB_SET_SS_BOS_DESCR, 0, (uint8_t *)USBBOSDscr);
    if (apiReturnStatus != CY_U3P_SUCCESS) {
        CyU3PDebugPrint(4, "domDupInitialiseApplication(): CyU3PUsbSetDesc BOS failed, Error code = %d\r\n", apiReturnStatus);
        domDupErrorHandler(apiReturnStatus);
    }

    // Device qualifier descriptor
    apiReturnStatus = CyU3PUsbSetDesc(CY_U3P_USB_SET_DEVQUAL_DESCR, 0, (uint8_t *)USBDeviceQualDscr);
    if (apiReturnStatus != CY_U3P_SUCCESS) {
        CyU3PDebugPrint(4, "domDupInitialiseApplication(): CyU3PUsbSetDesc qualifier descriptor failed, Error code = %d\r\n", apiReturnStatus);
        domDupErrorHandler(apiReturnStatus);
    }

    // Super speed configuration descriptor
    apiReturnStatus = CyU3PUsbSetDesc(CY_U3P_USB_SET_SS_CONFIG_DESCR, 0, (uint8_t *)USBSSConfigDscr);
    if (apiReturnStatus != CY_U3P_SUCCESS) {
        CyU3PDebugPrint(4, "domDupInitialiseApplication(): CyU3PUsbSetDesc configuration descriptor failed, Error code = %d\r\n", apiReturnStatus);
        domDupErrorHandler(apiReturnStatus);
    }

    // High speed configuration descriptor
    apiReturnStatus = CyU3PUsbSetDesc(CY_U3P_USB_SET_HS_CONFIG_DESCR, 0, (uint8_t *)USBHSConfigDscr);
    if (apiReturnStatus != CY_U3P_SUCCESS) {
        CyU3PDebugPrint(4, "domDupInitialiseApplication(): CyU3PUsbSetDesc Other Speed Descriptor failed, Error Code = %d\r\n", apiReturnStatus);
        domDupErrorHandler(apiReturnStatus);
    }

    // Full speed configuration descriptor
    apiReturnStatus = CyU3PUsbSetDesc(CY_U3P_USB_SET_FS_CONFIG_DESCR, 0, (uint8_t *)USBFSConfigDscr);
    if (apiReturnStatus != CY_U3P_SUCCESS) {
        CyU3PDebugPrint(4, "domDupInitialiseApplication(): CyU3PUsbSetDesc Full-Speed Descriptor failed, Error Code = %d\r\n", apiReturnStatus);
        domDupErrorHandler(apiReturnStatus);
    }

    // String descriptor 0
    apiReturnStatus = CyU3PUsbSetDesc(CY_U3P_USB_SET_STRING_DESCR, 0, (uint8_t *)USBStringLangIDDscr);
    if (apiReturnStatus != CY_U3P_SUCCESS) {
        CyU3PDebugPrint(4, "domDupInitialiseApplication(): CyU3PUsbSetDesc string 0 descriptor failed, Error code = %d\r\n", apiReturnStatus);
        domDupErrorHandler(apiReturnStatus);
    }

    // String descriptor 1
    apiReturnStatus = CyU3PUsbSetDesc(CY_U3P_USB_SET_STRING_DESCR, 1, (uint8_t *)USBManufactureDscr);
    if (apiReturnStatus != CY_U3P_SUCCESS) {
        CyU3PDebugPrint(4, "domDupInitialiseApplication(): CyU3PUsbSetDesc string descriptor 1 failed, Error code = %d\r\n", apiReturnStatus);
        domDupErrorHandler(apiReturnStatus);
    }

    // String descriptor 2
    apiReturnStatus = CyU3PUsbSetDesc(CY_U3P_USB_SET_STRING_DESCR, 2, (uint8_t *)USBProductDscr);
    if (apiReturnStatus != CY_U3P_SUCCESS)
    {
        CyU3PDebugPrint(4, "domDupInitialiseApplication(): CyU3PUsbSetDesc string descriptor 2 failed, Error code = %d\r\n", apiReturnStatus);
        domDupErrorHandler(apiReturnStatus);
    }

    // Show status in debug console
    CyU3PDebugPrint(4, "domDupInitialiseApplication(): Initialisation successful; Connecting to host\r\n");

    // Connect to the host
    if (!noRenum) {
        apiReturnStatus = CyU3PConnectState(CyTrue, CyTrue);
        if (apiReturnStatus != CY_U3P_SUCCESS) {
            CyU3PDebugPrint(4, "domDupInitialiseApplication(): CyU3PConnectState failed, Error code = %d\r\n", apiReturnStatus);
            domDupErrorHandler(apiReturnStatus);
        }
    } else {
    	// If application is already active.  Restart the application
        if (glIsApplnActive) domDupStopApplication();

        // Start the application
        domDupStartApplication();
    }
    CyU3PDebugPrint(8, "domDupInitialiseApplication(): Application initialisation complete.\r\n");
}
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

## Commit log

2019-09-01 Reorganisation of repository
    [ADC.sch, DdD Gain and filter calculations.xlsx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]
2019-09-02 Draft schematic for ADS825E module
    [ADC.sch, DomesdayDuplicator-base-DE0Nano.kicad_pcb, DomesdayDuplicator-base-DE0Nano.sch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]
2019-09-02 Added DdD base DE0-Nano connections and part mapping for ADS825 module
    [ADC.sch, DomesdayDuplicator-base-DE0Nano.sch, DomesdayDuplicator-module-ADS825.kicad_pcb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]
2019-09-02 Additional schematics for the base-board design + FX3 header parts
    [DomesdayDuplicator-base-DE0Nano.sch, cypress-fx3.sch, de0-nano.sch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]
2019-09-03 Fixes to module and base - added component mapping to base and verified mirrored headers
    [ADC.sch, DomesdayDuplicator-base-DE0Nano.kicad_pcb, DomesdayDuplicator-base-DE0Nano.sch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]
2019-09-04 Added protection resistors to module headers on the base-board
    [module-headers.sch]
2019-09-11 Work on the ADS825 module to determine the overall module dimensions and mounting
    [DomesdayDuplicator-base-DE0Nano.kicad_pcb, DomesdayDuplicator-module-ADS825.kicad_pcb, cypress-fx3.sch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]
2019-09-15 Mechanical set up of base board and basic routing
    [DomesdayDuplicator-base-DE0Nano.kicad_pcb, DomesdayDuplicator-module-ADS825.kicad_pcb, cypress-fx3.sch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]
2019-09-15 Finished base board ready for review
    [DomesdayDuplicator-base-DE0Nano.kicad_pcb]
2019-09-15 Added ld-decode logo
    [DomesdayDuplicator-base-DE0Nano.kicad_pcb]
2019-09-16 Added ADC module complete with routing
    [DomesdayDuplicator-base-DE0Nano.kicad_pcb, DomesdayDuplicator-module-ADS825.kicad_pcb, rf-front-end.sch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]
2025-09-22 Update to KiCad 9 and JLCPCB parts
    [ADC-2025-09-21-16-53-55.sch, ADC.kicad_sch, Domesday Duplicator-2025-09-21-16-53-55.sch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]

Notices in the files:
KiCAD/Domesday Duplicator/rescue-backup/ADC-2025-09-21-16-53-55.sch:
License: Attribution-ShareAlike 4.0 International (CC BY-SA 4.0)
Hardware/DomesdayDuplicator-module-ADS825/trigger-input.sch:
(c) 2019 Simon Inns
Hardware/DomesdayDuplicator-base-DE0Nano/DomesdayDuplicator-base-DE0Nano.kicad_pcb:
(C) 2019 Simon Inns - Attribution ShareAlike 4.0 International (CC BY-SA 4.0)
